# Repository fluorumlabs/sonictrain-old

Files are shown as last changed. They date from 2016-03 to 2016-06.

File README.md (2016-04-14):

# FluorumLabs / SonicTrain



This is the schematics and PCB repository for the second revision of SonicTrain: Hardware analog audio signal chain modules.

Version: 0.1-alpha2

Modules

Module | Revision | Status | Current Consumption (+15V / -15V) | Known issues
------ | -------- | ----------- | ------------ | ------- |
M101 Power Supply | B | Tested | | Polarity protection diode bridge is getting hot (50ºC) (#24)
M202 Stereo Input | C | Tested | 21mA / 35mA |
M303 Stereo Output | C | Tested | 31mA / 45mA |
M907 VU Meter | A | | |
M913 Dev Adapter | A | Tested | 5mA / 5mA | Blue LED is brighter then Red LED (#25)
A111 Fader | A | | |
A210 4-Band EQ | A | | |
A212 Kill EQ | A | | |
A405 Diode Distortion | A | Tested | 55mA / 60mA | Diodes should be connected to ground instead of OpAmp (#19), Output gain too low (#20)
A406 4069 Overdrive | A | | |
D104 LoFi Delay | A | Tested | |
D108 SpinSemi FX | A | Fail |  |
D709 VS1053 Synth | A | | |

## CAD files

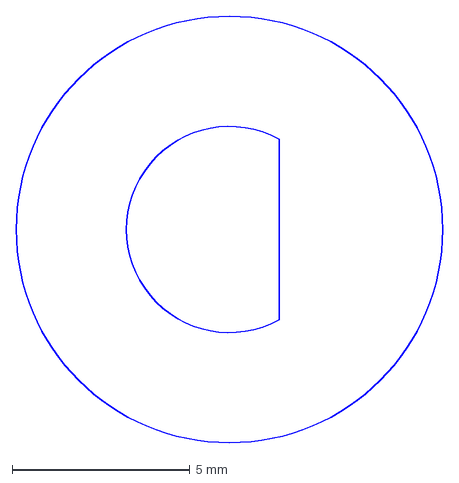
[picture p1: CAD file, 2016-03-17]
enclosure/w120-6045.dxf
12.0 x 12.0 mm

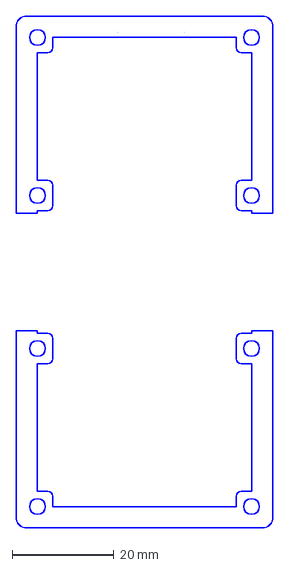
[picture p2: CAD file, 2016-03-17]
enclosure/z00003-5.dxf
50.4 x 100.4 mm

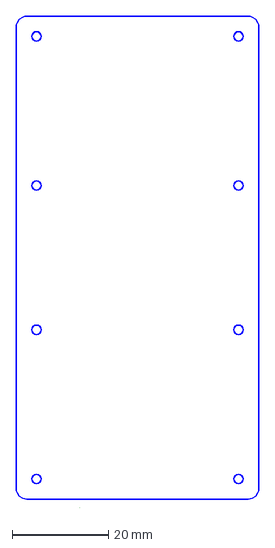
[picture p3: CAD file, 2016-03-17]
enclosure/z00001.dxf
50.4 x 102.2 mm

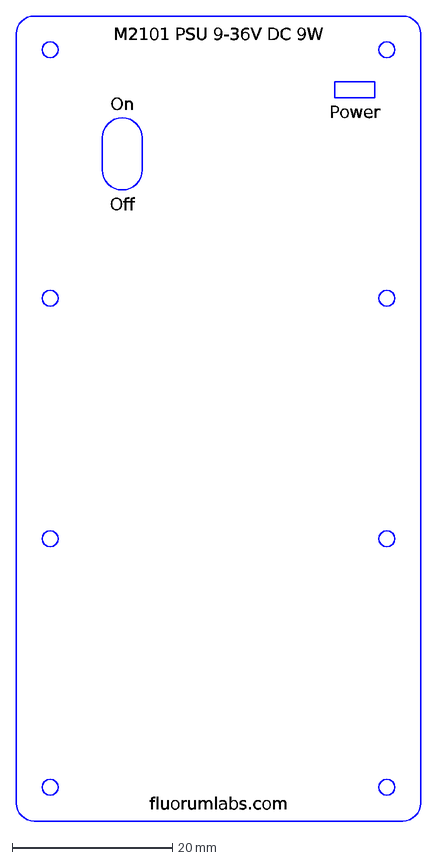
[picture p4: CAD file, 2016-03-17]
enclosure/m21016-switch.dxf
Power
fluorumlabs.com
M2101 PSU 9-36V DC 9W
On
Off

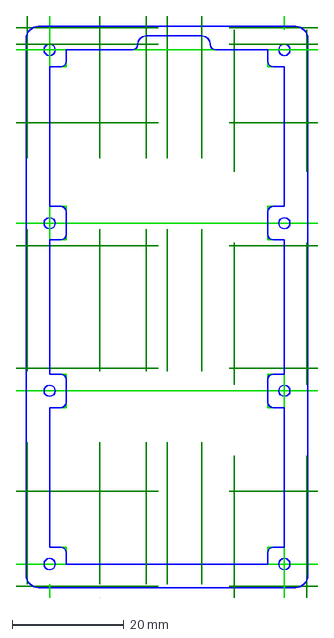
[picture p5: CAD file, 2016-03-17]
enclosure/m21012.dxf
54.0 x 104.0 mm

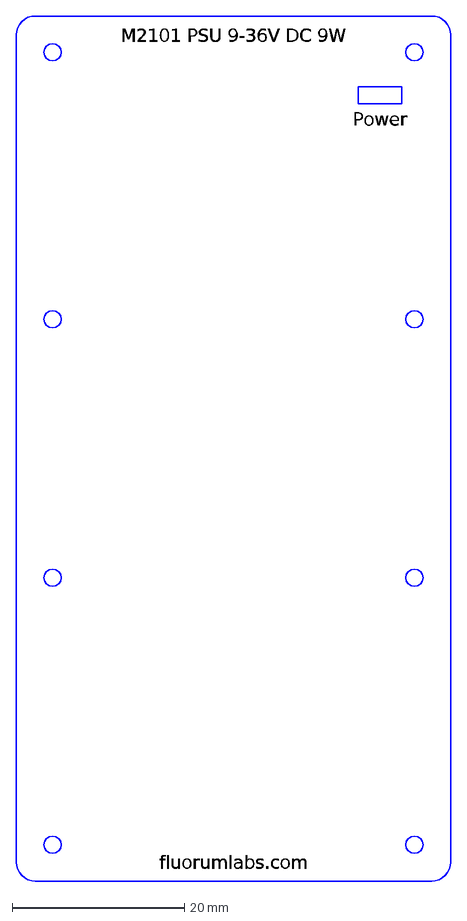
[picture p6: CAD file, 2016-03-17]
enclosure/m21016-no-switch.dxf
Power
fluorumlabs.com
M2101 PSU 9-36V DC 9W

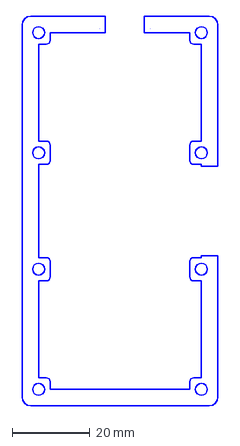
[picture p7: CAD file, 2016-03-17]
enclosure/m21013-5.dxf
50.4 x 100.4 mm

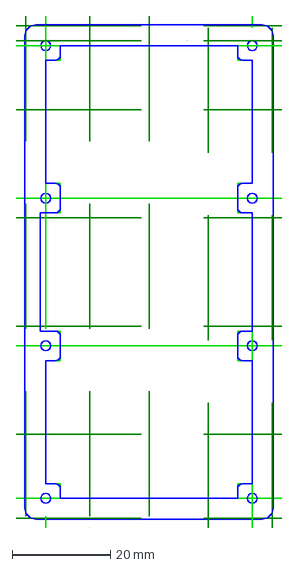
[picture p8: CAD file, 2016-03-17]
enclosure/z00002.dxf
54.0 x 104.0 mm

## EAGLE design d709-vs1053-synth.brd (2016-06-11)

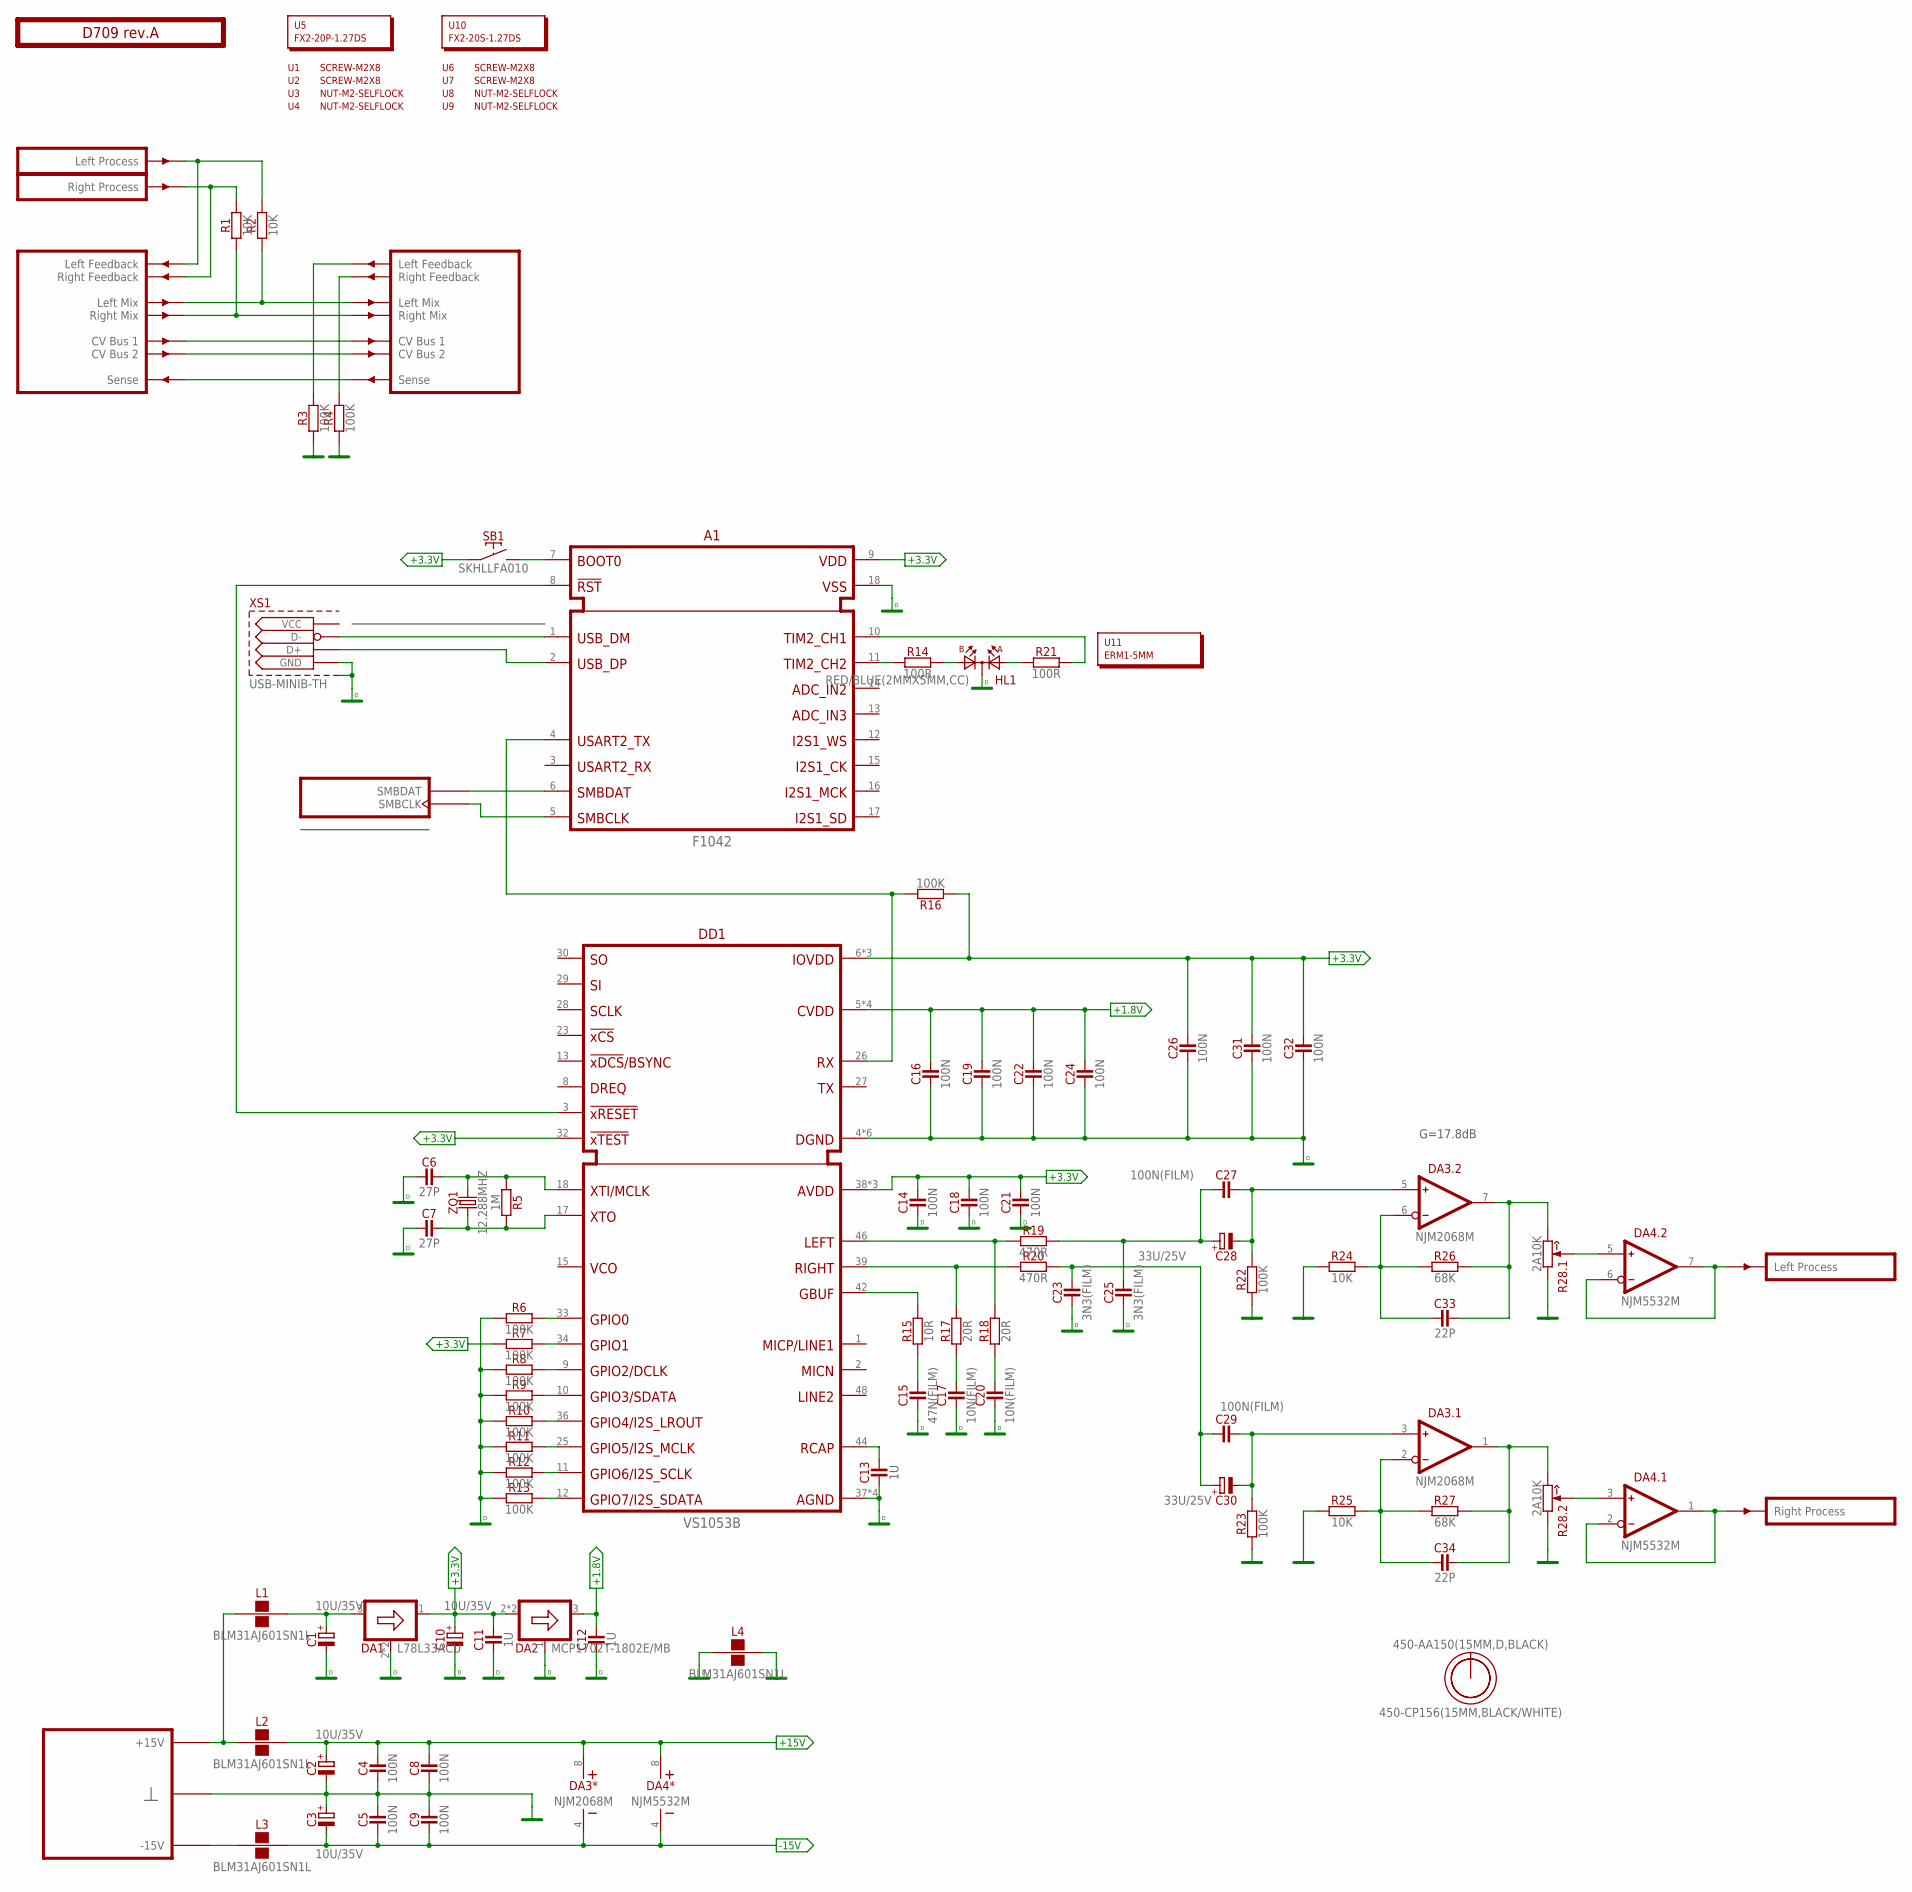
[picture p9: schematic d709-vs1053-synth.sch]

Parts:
A1: F1042; F-DIP18
C1, C2, C3, C10: 10U/35V; E2-5
C4, C5, C8, C9, C14, C16, C18, C19, C21, C22, C24, C26, C31, C32: 100N; C-0805
C6, C7: 27P; C-0805
C11, C12, C13: 1U; C-0805
C15: 47N(FILM); C050-025X075
C17, C20: 10N(FILM); C050-025X075
C23, C25: 3N3(FILM); C050-025X075
C27, C29: 100N(FILM); C050-025X075
C28, C30: 33U/25V; E2,5-7
C33, C34: 22P; C-0805
DA1: L78L33ACU; SOT89
DA2: MCP1702T-1802E/MB; SOT89
DA3: NJM2068M; SO-8
DA4: NJM5532M; SO-8
DD1: VS1053B; LQFP48-7X7
HL1: RED/BLUE(2MMX5MM,CC); LED2X5-3PIN
L1, L2, L3, L4: BLM31AJ601SN1L; 1206
O1: 450-AA150(15MM,D,BLACK); EMPTY
O2: 450-CP156(15MM,BLACK/WHITE); EMPTY
PCB1: D709 rev.A; ST2-BOARD-50
R1, R2, R24, R25: 10K; R-0805
R3, R4, R6, R7, R8, R9, R10, R11, R12, R13, R16, R22, R23: 100K; R-0805
R5: 1M; R-0805
R14, R21: 100R; R-0805
R15: 10R; R-0805
R17, R18: 20R; R-0805
R19, R20: 470R; R-0805
R26, R27: 68K; R-0805
R28: 2A10K; RV11-DUAL
SB1: SKHLLFA010
U1, U2, U6, U7: SCREW-M2X8; EMPTY
U3, U4, U8, U9: NUT-M2-SELFLOCK; EMPTY
U5: FX2-20P-1.27DS; EMPTY
U10: FX2-20S-1.27DS; EMPTY
U11: ERM1-5MM; EMPTY
XS1: USB-MINIB-TH; USB-MB-H
ZQ1: 12.288MHZ; 3225

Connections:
+1.8V: C12.2, C16.2, C19.2, C22.2, C24.2, DA2.3 (OUT), DD1.5 (CVDD), DD1.7 (CVDD), DD1.24 (CVDD), DD1.31 (CVDD)
+3.3V: A1.9 (VDD), C10.+, C11.2, C14.2, C18.2, C21.2, C26.2, C31.2, C32.2, DA1.1 (OUT), DA2.2 (IN), DA2.2@1 (IN), DD1.6 (IOVDD), DD1.14 (IOVDD), DD1.19 (IOVDD), DD1.32 (!XTEST), DD1.38 (AVDD), DD1.43 (AVDD), DD1.45 (AVDD), R7.1, R16.1, SB1.1
+15V: C2.+, C4.2, C8.2, DA3.8 (V+), DA4.8 (V+), L2.2
-15V: C3.-, C5.1, C9.1, DA3.4 (V-), DA4.4 (V-), L3.2
DGND: A1.18 (VSS), C1.-, C6.1, C7.1, C10.-, C11.1, C12.1, C13.1, C14.1, C15.1, C16.1, C17.1, C18.1, C19.1, C20.1, C21.1, C22.1, C23.1, C24.1, C25.1, C26.1, C31.1, C32.1, DA1.2 (GND), DA1.2@1 (GND), DA2.1 (GND), DD1.4 (DGND), DD1.16 (DGND), DD1.20 (DGND), DD1.21 (DGND), DD1.22 (DGND), DD1.35 (DGND), DD1.37 (AGND), DD1.40 (AGND), DD1.41 (AGND), DD1.47 (AGND), HL1.K, L4.1, R6.1, R8.1, R9.1, R10.1, R11.1, R12.1, R13.1, XS1.GND, XS1.P$1 (S1), XS1.P$2 (S1), XS1.P$6 (S1), XS1.P$7 (S1)
GND: C2.-, C3.+, C4.1, C5.2, C8.1, C9.2, L4.2, PCB1.B4 (GND), PCB1.B4' (GND), PCB1.B5 (GND), PCB1.B5' (GND), PCB1.B6 (GND), PCB1.B6' (GND), PCB1.B7 (GND), PCB1.B7' (GND), PCB1.B8 (GND), PCB1.B8' (GND), R3.1, R4.1, R22.1, R23.1, R24.1, R25.1, R28.1 (CCW), R28.1' (CCW)
LMIX: PCB1.ALMIX (LMIX), PCB1.ALMIX' (LMIX'), R2.1
unnamed: L1.1, L2.1, PCB1.A+15 (P+15V), PCB1.A+15' (P+15V), PCB1.B+15 (P+15V), PCB1.B+15' (P+15V)
unnamed: PCB1.ARFBK' (RFBK'), R4.2
unnamed: A1.7 (BOOT0), SB1.2
unnamed: PCB1.ALFBK' (LFBK'), R3.2
unnamed: L3.1, PCB1.A-15 (P-15V), PCB1.A-15' (P-15V), PCB1.B-15 (P-15V), PCB1.B-15' (P-15V)
unnamed: C25.2, C27.1, C28.+, R19.2
unnamed: C29.2, C30.-, DA3.3 (IN+), R23.2
unnamed: C27.2, C28.-, DA3.5 (IN+), R22.2
unnamed: C34.2, DA3.1 (OUT), R27.2, R28.3' (CW)
unnamed: C33.2, DA3.7 (OUT), R26.2, R28.3 (CW)
unnamed: C33.1, DA3.6 (IN-), R24.2, R26.1
unnamed: C34.1, DA3.2 (IN-), R25.2, R27.1
unnamed: PCB1.BSENSE (SENSE), PCB1.BSENSE' (SENSE')
unnamed: C7.2, DD1.17 (XTO), R5.2, ZQ1.1
unnamed: DA4.6 (IN-), DA4.7 (OUT), PCB1.BOUTL' (OUTL)
unnamed: DA4.1 (OUT), DA4.2 (IN-), PCB1.BOUTR' (OUTR)
unnamed: DA4.5 (IN+), R28.2 (W)
unnamed: DA4.3 (IN+), R28.2' (W)
unnamed: C1.+, DA1.3 (IN), L1.2
unnamed: C6.2, DD1.18 (XTI/MCLK), R5.1, ZQ1.3 (2)
unnamed: C23.2, C29.1, C30.+, R20.2
unnamed: PCB1.ARFBK (RFBK), PCB1.BINR (INR), R1.2
unnamed: PCB1.ALFBK (LFBK), PCB1.BINL (INL), R2.2
unnamed: PCB1.ACV1 (CV1), PCB1.ACV1' (CV1')
unnamed: PCB1.ACV2 (CV2), PCB1.ACV2' (CV2')
unnamed: A1.8 (!RST), DD1.3 (!XRESET)
unnamed: DD1.12 (GPIO7/I2S_SDATA), R13.2
unnamed: DD1.11 (GPIO6/I2S_SCLK), R12.2
unnamed: DD1.25 (GPIO5/I2S_MCLK), R11.2
unnamed: A1.4 (USART2_TX), DD1.26 (RX), R16.2
unnamed: DD1.36 (GPIO4/I2S_LROUT), R10.2
unnamed: DD1.10 (GPIO3/SDATA), R9.2
unnamed: DD1.9 (GPIO2/DCLK), R8.2
unnamed: DD1.34 (GPIO1), R7.2
unnamed: DD1.33 (GPIO0), R6.2
unnamed: C13.2, DD1.44 (RCAP)
unnamed: A1.11 (TIM2_CH2), R14.1
unnamed: C15.2, R15.1
unnamed: HL1.A2, R14.2
unnamed: DD1.42 (GBUF), R15.2
unnamed: DD1.39 (RIGHT), R17.2, R20.1
unnamed: C17.2, R17.1
unnamed: DD1.46 (LEFT), R18.2, R19.1
unnamed: C20.2, R18.1
unnamed: HL1.A1, R21.1
unnamed: A1.10 (TIM2_CH1), R21.2
RMIX: PCB1.ARMIX (RMIX), PCB1.ARMIX' (RMIX'), R1.1
SMBCLK: A1.5 (SMBCLK), PCB1.ASMBCLK (SMBCLK), PCB1.ASMBCLK' (SMBCLK)
SMBDAT: A1.6 (SBMDAT), PCB1.ASMBDAT (SMBDAT), PCB1.ASMBDAT' (SMBDAT)
USB_N: A1.1 (USB_DM), XS1.D-
USB_P: A1.2 (USB_DP), XS1.D+

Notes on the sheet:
G=17.8dB

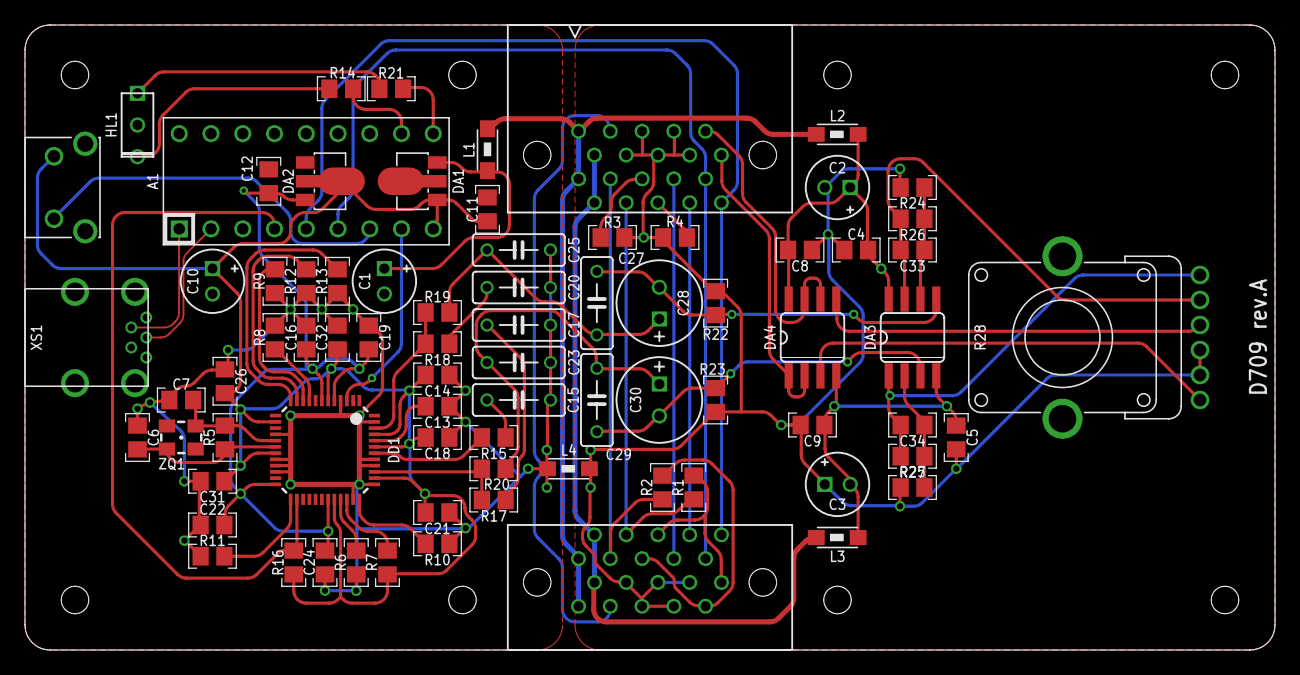
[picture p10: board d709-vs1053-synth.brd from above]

Board: 2 copper layers, 100.0 x 50.0 mm, 90 parts (0 on the bottom side), 58 nets.

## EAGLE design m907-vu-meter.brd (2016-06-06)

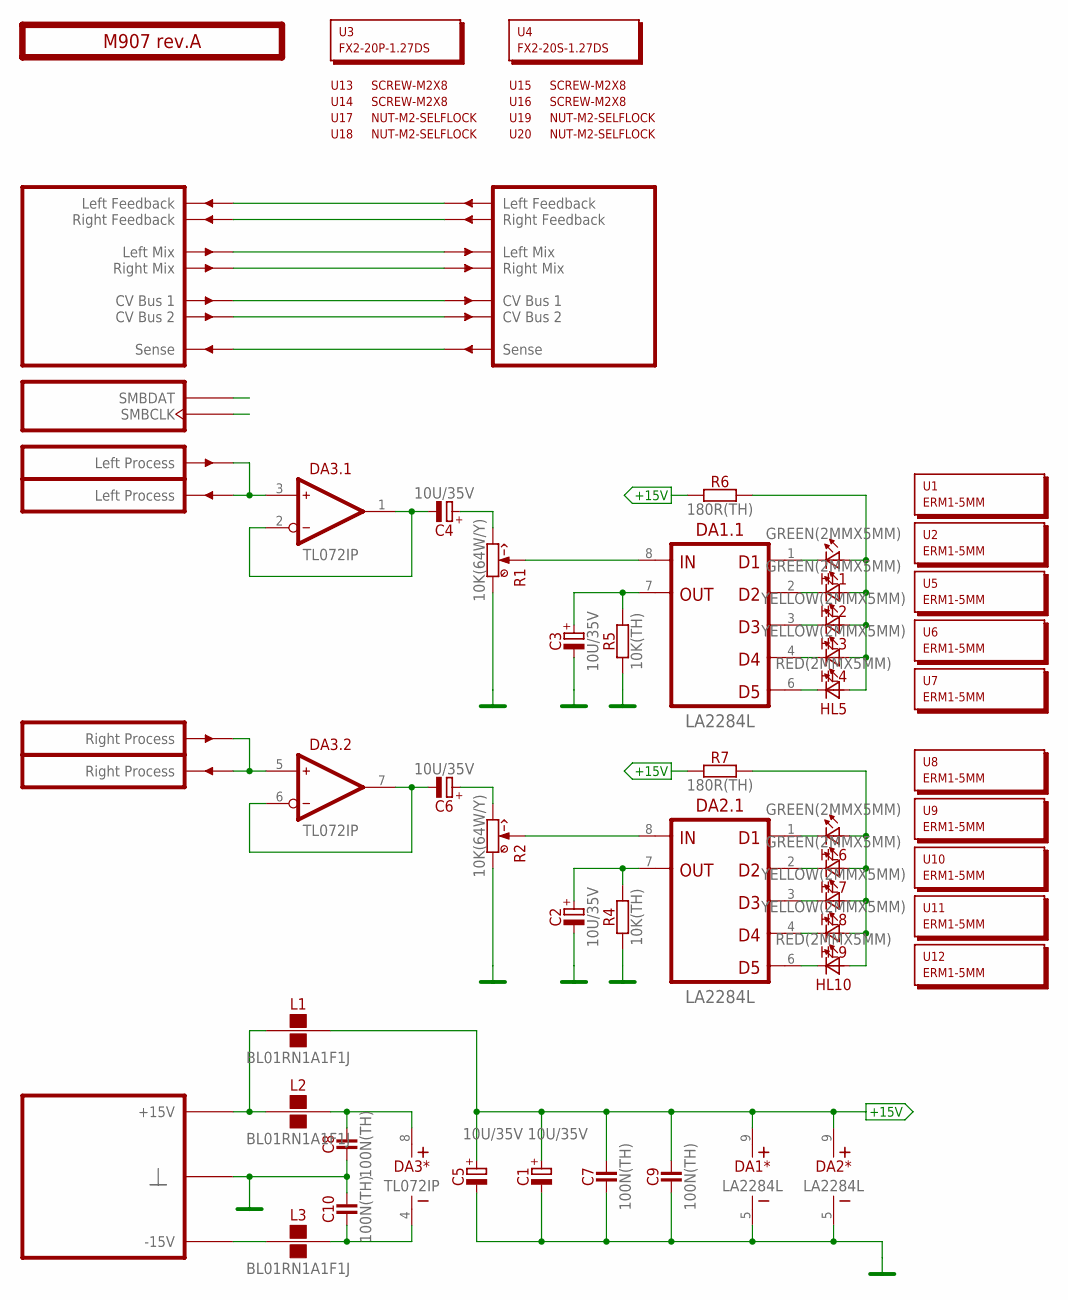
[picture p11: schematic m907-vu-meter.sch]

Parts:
C1, C2, C3, C4, C5, C6: 10U/35V; E2-5
C7, C8, C9, C10: 100N(TH); C050-024X044
DA1, DA2: LA2284L; SIL9
DA3: TL072IP; DIP-8
HL1, HL2, HL6, HL7: GREEN(2MMX5MM); LED2X5
HL3, HL4, HL8, HL9: YELLOW(2MMX5MM); LED2X5
HL5, HL10: RED(2MMX5MM); LED2X5
L1, L2, L3: BL01RN1A1F1J; BL01RN1A
PCB1: M907 rev.A; ST2-BOARD-26
R1, R2: 10K(64W/Y); 64W
R4, R5: 10K(TH); R-0207/10
R6, R7: 180R(TH); R-0207/10
U1, U2, U5, U6, U7, U8, U9, U10, U11, U12: ERM1-5MM; EMPTY
U3: FX2-20P-1.27DS; EMPTY
U4: FX2-20S-1.27DS; EMPTY
U13, U14, U15, U16: SCREW-M2X8; EMPTY
U17, U18, U19, U20: NUT-M2-SELFLOCK; EMPTY

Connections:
+15V: C1.+, C5.+, C7.2, C9.2, DA1.9 (V+), DA2.9 (V+), L1.2, R6.1, R7.1
GND: C1.-, C2.-, C3.-, C5.-, C7.1, C8.1, C9.1, C10.2, DA1.5 (V-), DA2.5 (V-), PCB1.B4 (GND), PCB1.B4' (GND), PCB1.B5 (GND), PCB1.B5' (GND), PCB1.B6 (GND), PCB1.B6' (GND), PCB1.B7 (GND), PCB1.B7' (GND), PCB1.B8 (GND), PCB1.B8' (GND), R1.1 (CCW), R2.1 (CCW), R4.1, R5.1
LMIX: PCB1.ALMIX (LMIX), PCB1.ALMIX' (LMIX')
unnamed: L1.1, L2.1, PCB1.A+15 (P+15V), PCB1.A+15' (P+15V), PCB1.B+15 (P+15V), PCB1.B+15' (P+15V)
unnamed: PCB1.ALFBK (LFBK), PCB1.ALFBK' (LFBK')
unnamed: DA2.8 (IN), R2.S (W), R2.S@1 (W)
unnamed: PCB1.ARFBK (RFBK), PCB1.ARFBK' (RFBK')
unnamed: DA1.8 (IN), R1.S (W), R1.S@1 (W)
unnamed: C3.+, DA1.7 (OUT), R5.2
unnamed: C2.+, DA2.7 (OUT), R4.2
unnamed: HL1.A, HL2.A, HL3.A, HL4.A, HL5.A, R6.2
unnamed: DA1.1 (D1), HL1.K (C)
unnamed: DA1.2 (D2), HL2.K (C)
unnamed: DA1.3 (D3), HL3.K (C)
unnamed: DA1.4 (D4), HL4.K (C)
unnamed: DA1.6 (D5), HL5.K (C)
unnamed: HL6.A, HL7.A, HL8.A, HL9.A, HL10.A, R7.2
unnamed: DA2.1 (D1), HL6.K (C)
unnamed: PCB1.BSENSE (SENSE), PCB1.BSENSE' (SENSE')
unnamed: DA2.2 (D2), HL7.K (C)
unnamed: DA2.3 (D3), HL8.K (C)
unnamed: DA2.4 (D4), HL9.K (C)
unnamed: DA2.6 (D5), HL10.K (C)
unnamed: C4.+, R1.3 (CW)
unnamed: C6.+, R2.3 (CW)
unnamed: DA3.3 (IN+), PCB1.BINL (INL), PCB1.BOUTL' (OUTL)
unnamed: DA3.5 (IN+), PCB1.BINR (INR), PCB1.BOUTR' (OUTR)
unnamed: L3.1, PCB1.A-15 (P-15V), PCB1.A-15' (P-15V), PCB1.B-15 (P-15V), PCB1.B-15' (P-15V)
unnamed: C8.2, DA3.8 (V+), L2.2
unnamed: C10.1, DA3.4 (V-), L3.2
unnamed: C4.-, DA3.1 (OUT), DA3.2 (IN-)
unnamed: C6.-, DA3.6 (IN-), DA3.7 (OUT)
unnamed: PCB1.ASMBDAT (SMBDAT), PCB1.ASMBDAT' (SMBDAT)
unnamed: PCB1.ACV1 (CV1), PCB1.ACV1' (CV1')
unnamed: PCB1.ACV2 (CV2), PCB1.ACV2' (CV2')
unnamed: PCB1.ASMBCLK (SMBCLK), PCB1.ASMBCLK' (SMBCLK)
RMIX: PCB1.ARMIX (RMIX), PCB1.ARMIX' (RMIX')

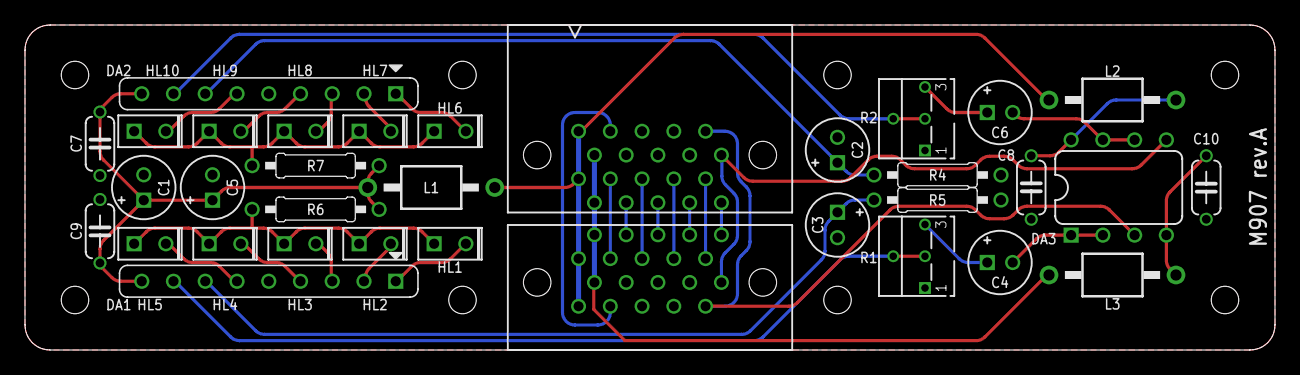
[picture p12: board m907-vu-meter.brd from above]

Board: 2 copper layers, 100.0 x 26.0 mm, 53 parts (0 on the bottom side), 37 nets.

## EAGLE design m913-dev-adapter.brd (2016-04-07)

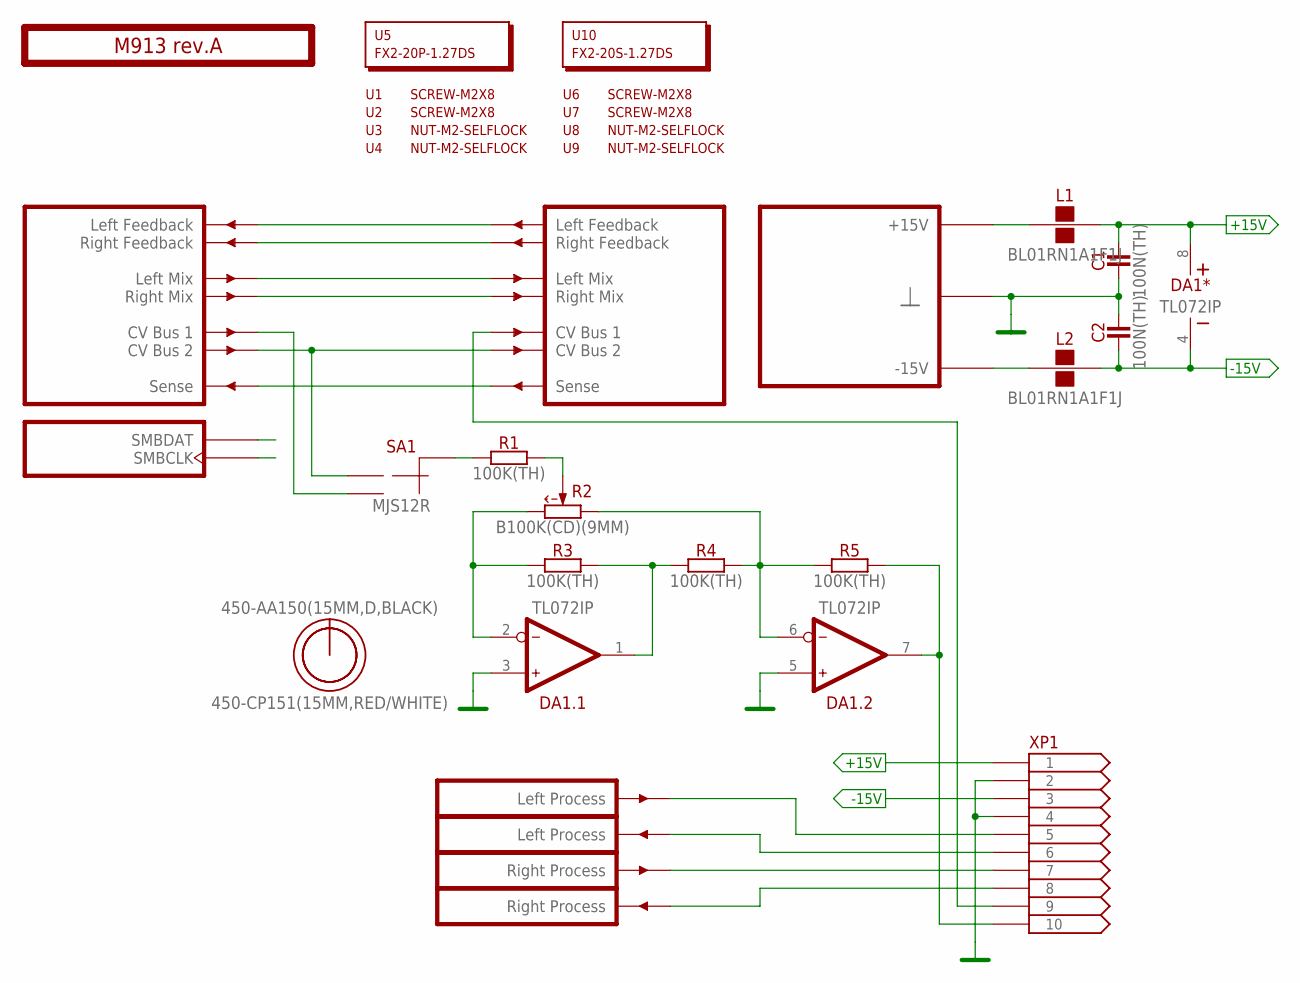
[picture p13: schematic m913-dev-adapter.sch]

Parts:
C1, C2: 100N(TH); C050-024X044
DA1: TL072IP; DIP-8
L1, L2: BL01RN1A1F1J; BL01RN1A
O1: 450-AA150(15MM,D,BLACK); EMPTY
O2: 450-CP151(15MM,RED/WHITE); EMPTY
PCB1: M913 rev.A; ST2-BOARD-26
R1, R3, R4, R5: 100K(TH); R-0207/10
R2: B100K(CD)(9MM); RV09-SINGLE
SA1: MJS12R; APEM-MJS12R
U1, U2, U6, U7: SCREW-M2X8; EMPTY
U3, U4, U8, U9: NUT-M2-SELFLOCK; EMPTY
U5: FX2-20P-1.27DS; EMPTY
U10: FX2-20S-1.27DS; EMPTY
XP1: CONN-10-IDC; ML10

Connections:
+15V: C1.2, DA1.8 (V+), L1.2, XP1.1
-15V: C2.1, DA1.4 (V-), L2.2, XP1.3
GND: C1.1, C2.2, DA1.3 (IN+), DA1.5 (IN+), PCB1.B4 (GND), PCB1.B4' (GND), PCB1.B5 (GND), PCB1.B5' (GND), PCB1.B6 (GND), PCB1.B6' (GND), PCB1.B7 (GND), PCB1.B7' (GND), PCB1.B8 (GND), PCB1.B8' (GND), XP1.2, XP1.4
LMIX: PCB1.ALMIX (LMIX), PCB1.ALMIX' (LMIX')
unnamed: L1.1, PCB1.A+15 (P+15V), PCB1.A+15' (P+15V), PCB1.B+15 (P+15V), PCB1.B+15' (P+15V)
unnamed: PCB1.ALFBK (LFBK), PCB1.ALFBK' (LFBK')
unnamed: R1.2, R2.2 (W)
unnamed: PCB1.ARFBK (RFBK), PCB1.ARFBK' (RFBK')
unnamed: DA1.2 (IN-), R2.3 (CW), R3.1
unnamed: DA1.1 (OUT), R3.2, R4.1
unnamed: DA1.6 (IN-), R2.1 (CCW), R4.2, R5.1
unnamed: DA1.7 (OUT), R5.2, XP1.10
unnamed: R1.1, SA1.C (CM)
unnamed: PCB1.BINL (INL), XP1.5
unnamed: PCB1.BOUTL' (OUTL), XP1.6
unnamed: PCB1.BINR (INR), XP1.7
unnamed: PCB1.BOUTR' (OUTR), XP1.8
unnamed: PCB1.ACV1' (CV1'), XP1.9
unnamed: PCB1.ACV1 (CV1), SA1.NO (2)
unnamed: PCB1.BSENSE (SENSE), PCB1.BSENSE' (SENSE')
unnamed: L2.1, PCB1.A-15 (P-15V), PCB1.A-15' (P-15V), PCB1.B-15 (P-15V), PCB1.B-15' (P-15V)
unnamed: PCB1.ASMBDAT (SMBDAT), PCB1.ASMBDAT' (SMBDAT)
unnamed: PCB1.ACV2 (CV2), PCB1.ACV2' (CV2'), SA1.NC (1)
unnamed: PCB1.ASMBCLK (SMBCLK), PCB1.ASMBCLK' (SMBCLK)
RMIX: PCB1.ARMIX (RMIX), PCB1.ARMIX' (RMIX')

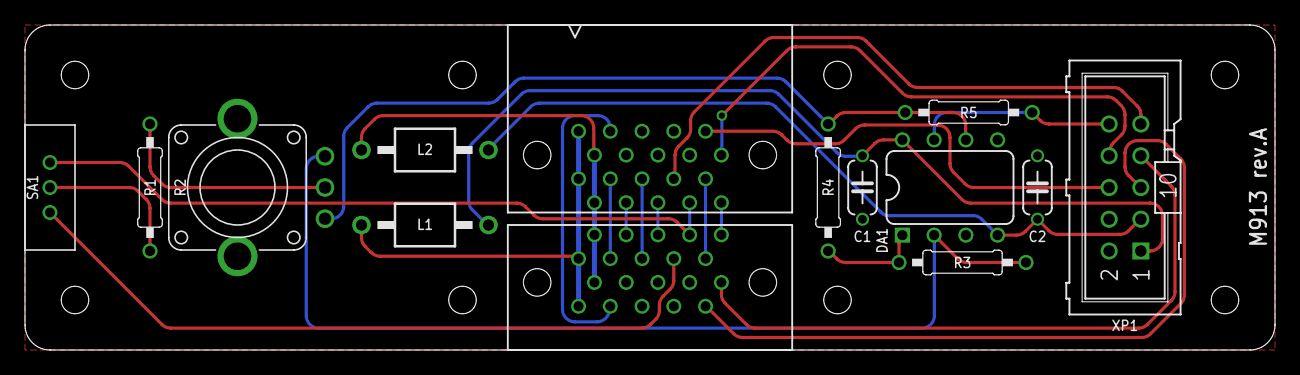
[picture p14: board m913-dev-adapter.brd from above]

Board: 2 copper layers, 100.0 x 26.0 mm, 25 parts (0 on the bottom side), 25 nets.

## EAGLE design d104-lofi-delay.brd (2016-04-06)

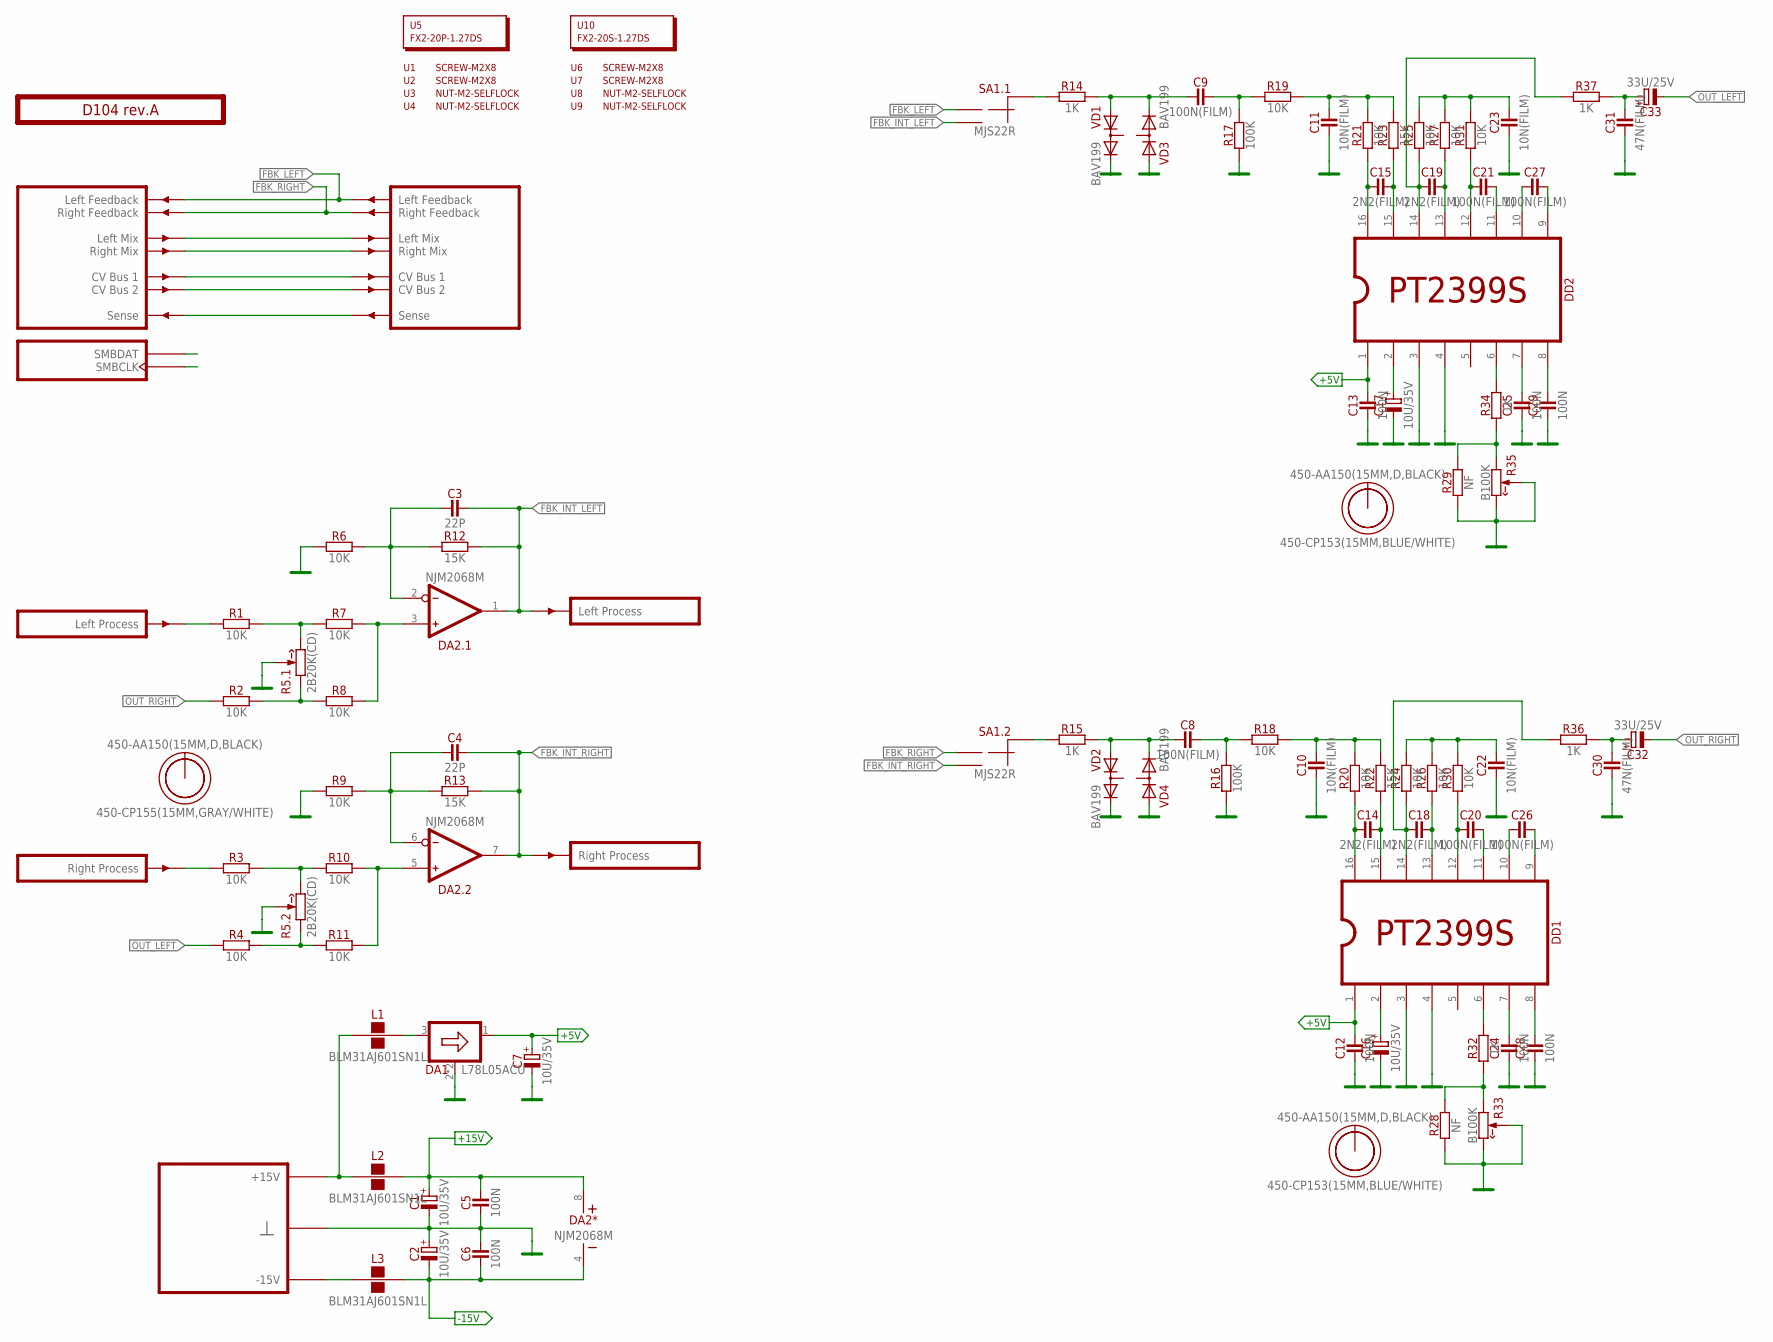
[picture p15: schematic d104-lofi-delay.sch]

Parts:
C1, C2, C7, C16, C17: 10U/35V; E2-5
C3, C4: 22P; C-0805
C5, C6, C12, C13, C24, C25, C28, C29: 100N; C-0805
C8, C9, C20, C21, C26, C27: 100N(FILM); C050-025X075
C10, C11, C22, C23: 10N(FILM); C050-025X075
C14, C15, C18, C19: 2N2(FILM); C050-025X075
C30, C31: 47N(FILM); C050-025X075
C32, C33: 33U/25V; E2,5-7
DA1: L78L05ACU; SOT89
DA2: NJM2068M; SO-8
DD1, DD2: PT2399S; SO-16; PARTNO *
L1, L2, L3: BLM31AJ601SN1L; 1206
O1, O3, O5: 450-AA150(15MM,D,BLACK); EMPTY
O2: 450-CP155(15MM,GRAY/WHITE); EMPTY
O4, O6: 450-CP153(15MM,BLUE/WHITE); EMPTY
PCB1: D104 rev.A; ST2-BOARD-50
R1, R2, R3, R4, R6, R7, R8, R9, R10, R11, R18, R19, R20, R21, R24, R25, R26, R27, R30, R31: 10K; R-0805
R5: 2B20K(CD); RV11-DUAL
R12, R13, R22, R23: 15K; R-0805
R14, R15, R32, R34, R36, R37: 1K; R-0805
R16, R17: 100K; R-0805
R28, R29: NF; R-0805
R33, R35: B100K; RV11-SINGLE
SA1: MJS22R; APEM-MJS22R
U1, U2, U6, U7: SCREW-M2X8; EMPTY
U3, U4, U8, U9: NUT-M2-SELFLOCK; EMPTY
U5: FX2-20P-1.27DS; EMPTY
U10: FX2-20S-1.27DS; EMPTY
VD1, VD2, VD3, VD4: BAV199; SOT23

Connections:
+5V: C7.+, C12.2, C13.2, DA1.1 (OUT), DD1.1, DD2.1
+15V: C1.+, C5.2, DA2.8 (V+), L2.2
-15V: C2.-, C6.1, DA2.4 (V-), L3.2
FBK_INT_LEFT: C3.2, DA2.1 (OUT), PCB1.BOUTL' (OUTL), R12.2, SA1.NO1 (2)
FBK_INT_RIGHT: C4.2, DA2.7 (OUT), PCB1.BOUTR' (OUTR), R13.2, SA1.NO2 (2)
FBK_LEFT: PCB1.ALFBK (LFBK), PCB1.ALFBK' (LFBK'), SA1.NC1 (1)
FBK_RIGHT: PCB1.ARFBK (RFBK), PCB1.ARFBK' (RFBK'), SA1.NC2 (1)
GND: C1.-, C2.+, C5.1, C6.2, C7.-, C10.1, C11.1, C12.1, C13.1, C16.-, C17.-, C22.1, C23.1, C24.1, C25.1, C28.1, C29.1, C30.1, C31.1, DA1.2 (GND), DA1.2@1 (GND), DD1.3, DD1.4, DD2.3, DD2.4, PCB1.B4 (GND), PCB1.B4' (GND), PCB1.B5 (GND), PCB1.B5' (GND), PCB1.B6 (GND), PCB1.B6' (GND), PCB1.B7 (GND), PCB1.B7' (GND), PCB1.B8 (GND), PCB1.B8' (GND), R5.2 (W), R5.2' (W), R6.1, R9.1, R16.1, R17.1, R28.1, R29.1, R33.2 (W), R33.3 (CW), R35.2 (W), R35.3 (CW), VD1.2 (C), VD2.2 (C), VD3.1 (A), VD4.1 (A)
LMIX: PCB1.ALMIX (LMIX), PCB1.ALMIX' (LMIX')
unnamed: R29.2, R34.1, R35.1 (CCW)
unnamed: R28.2, R32.1, R33.1 (CCW)
unnamed: C9.1, R14.2, VD1.1 (A), VD3.2 (C)
unnamed: C15.1, DD2.16, R21.1
unnamed: C8.1, R15.2, VD2.1 (A), VD4.2 (C)
unnamed: R14.1, SA1.C1 (CM)
unnamed: R3.2, R5.3' (CW), R10.1
unnamed: C9.2, R17.2, R19.1
unnamed: C11.2, R19.2, R21.2, R23.2
unnamed: PCB1.BINL (INL), R1.1
unnamed: R15.1, SA1.C2 (CM)
unnamed: C23.2, R25.2, R27.2, R31.2
unnamed: PCB1.BSENSE (SENSE), PCB1.BSENSE' (SENSE')
unnamed: C15.2, DD2.15, R23.1
unnamed: C19.1, DD2.14, R25.1, R37.1
unnamed: C19.2, DD2.13, R27.1
unnamed: C21.1, DD2.12, R31.1
unnamed: C21.2, DD2.11
unnamed: C27.1, DD2.10
unnamed: C27.2, DD2.9
unnamed: C31.2, C33.+, R37.2
unnamed: C4.1, DA2.6 (IN-), R9.2, R13.1
unnamed: PCB1.BINR (INR), R3.1
unnamed: R1.2, R5.3 (CW), R7.1
unnamed: C25.2, DD2.7
unnamed: C29.2, DD2.8
unnamed: DD2.6, R34.2
unnamed: L3.1, PCB1.A-15 (P-15V), PCB1.A-15' (P-15V), PCB1.B-15 (P-15V), PCB1.B-15' (P-15V)
unnamed: C17.+, DD2.2
unnamed: PCB1.ASMBDAT (SMBDAT), PCB1.ASMBDAT' (SMBDAT)
unnamed: DA2.5 (IN+), R10.2, R11.2
unnamed: R4.2, R5.1' (CCW), R11.1
unnamed: PCB1.ACV1 (CV1), PCB1.ACV1' (CV1')
unnamed: PCB1.ACV2 (CV2), PCB1.ACV2' (CV2')
unnamed: PCB1.ASMBCLK (SMBCLK), PCB1.ASMBCLK' (SMBCLK)
unnamed: DA1.3 (IN), L1.2
unnamed: C22.2, R24.2, R26.2, R30.2
unnamed: C14.1, DD1.16, R20.1
unnamed: C14.2, DD1.15, R22.1
unnamed: C18.1, DD1.14, R24.1, R36.1
unnamed: C18.2, DD1.13, R26.1
unnamed: C20.1, DD1.12, R30.1
unnamed: C20.2, DD1.11
unnamed: C26.1, DD1.10
unnamed: C26.2, DD1.9
unnamed: C30.2, C32.+, R36.2
unnamed: C24.2, DD1.7
unnamed: C28.2, DD1.8
unnamed: DD1.6, R32.2
unnamed: DA2.3 (IN+), R7.2, R8.2
unnamed: C8.2, R16.2, R18.1
unnamed: C10.2, R18.2, R20.2, R22.2
unnamed: C3.1, DA2.2 (IN-), R6.2, R12.1
unnamed: R2.2, R5.1 (CCW), R8.1
unnamed: C16.+, DD1.2
OUT_LEFT: C33.-, R4.1
OUT_RIGHT: C32.-, R2.1
P+15V: L1.1, L2.1, PCB1.A+15 (P+15V), PCB1.A+15' (P+15V), PCB1.B+15 (P+15V), PCB1.B+15' (P+15V)
RMIX: PCB1.ARMIX (RMIX), PCB1.ARMIX' (RMIX')

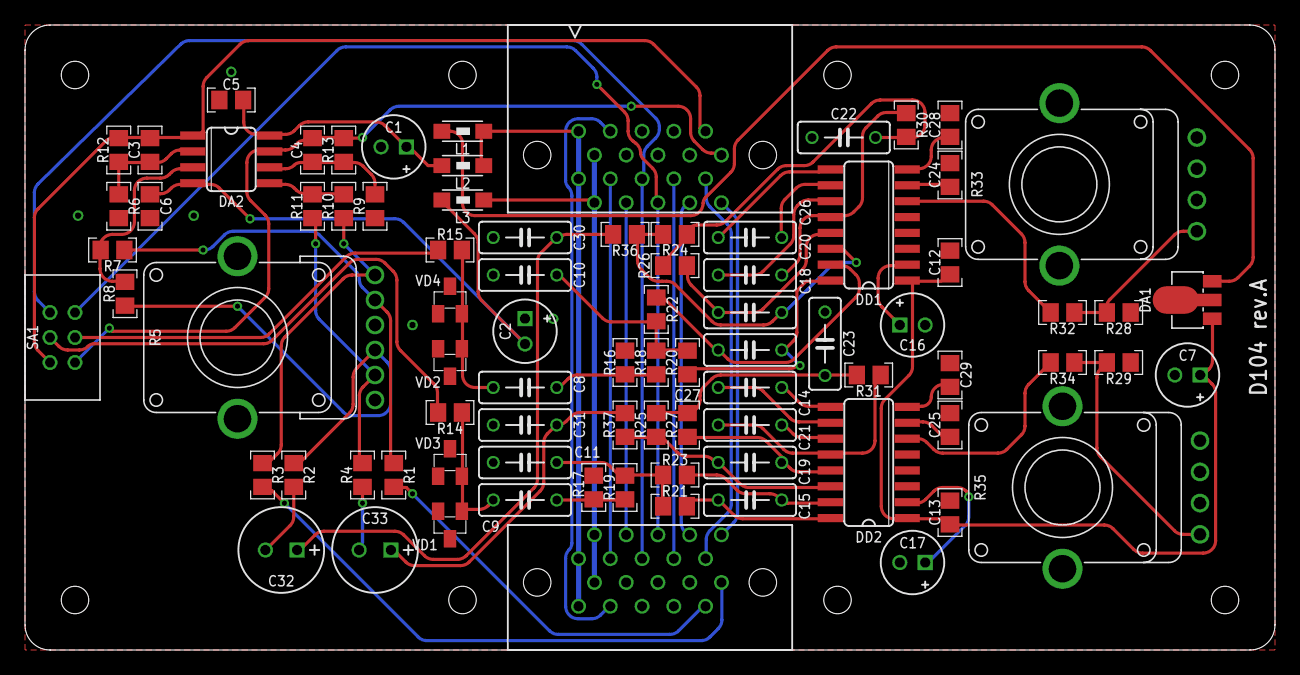
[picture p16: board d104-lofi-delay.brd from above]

Board: 2 copper layers, 100.0 x 50.0 mm, 99 parts (0 on the bottom side), 68 nets.

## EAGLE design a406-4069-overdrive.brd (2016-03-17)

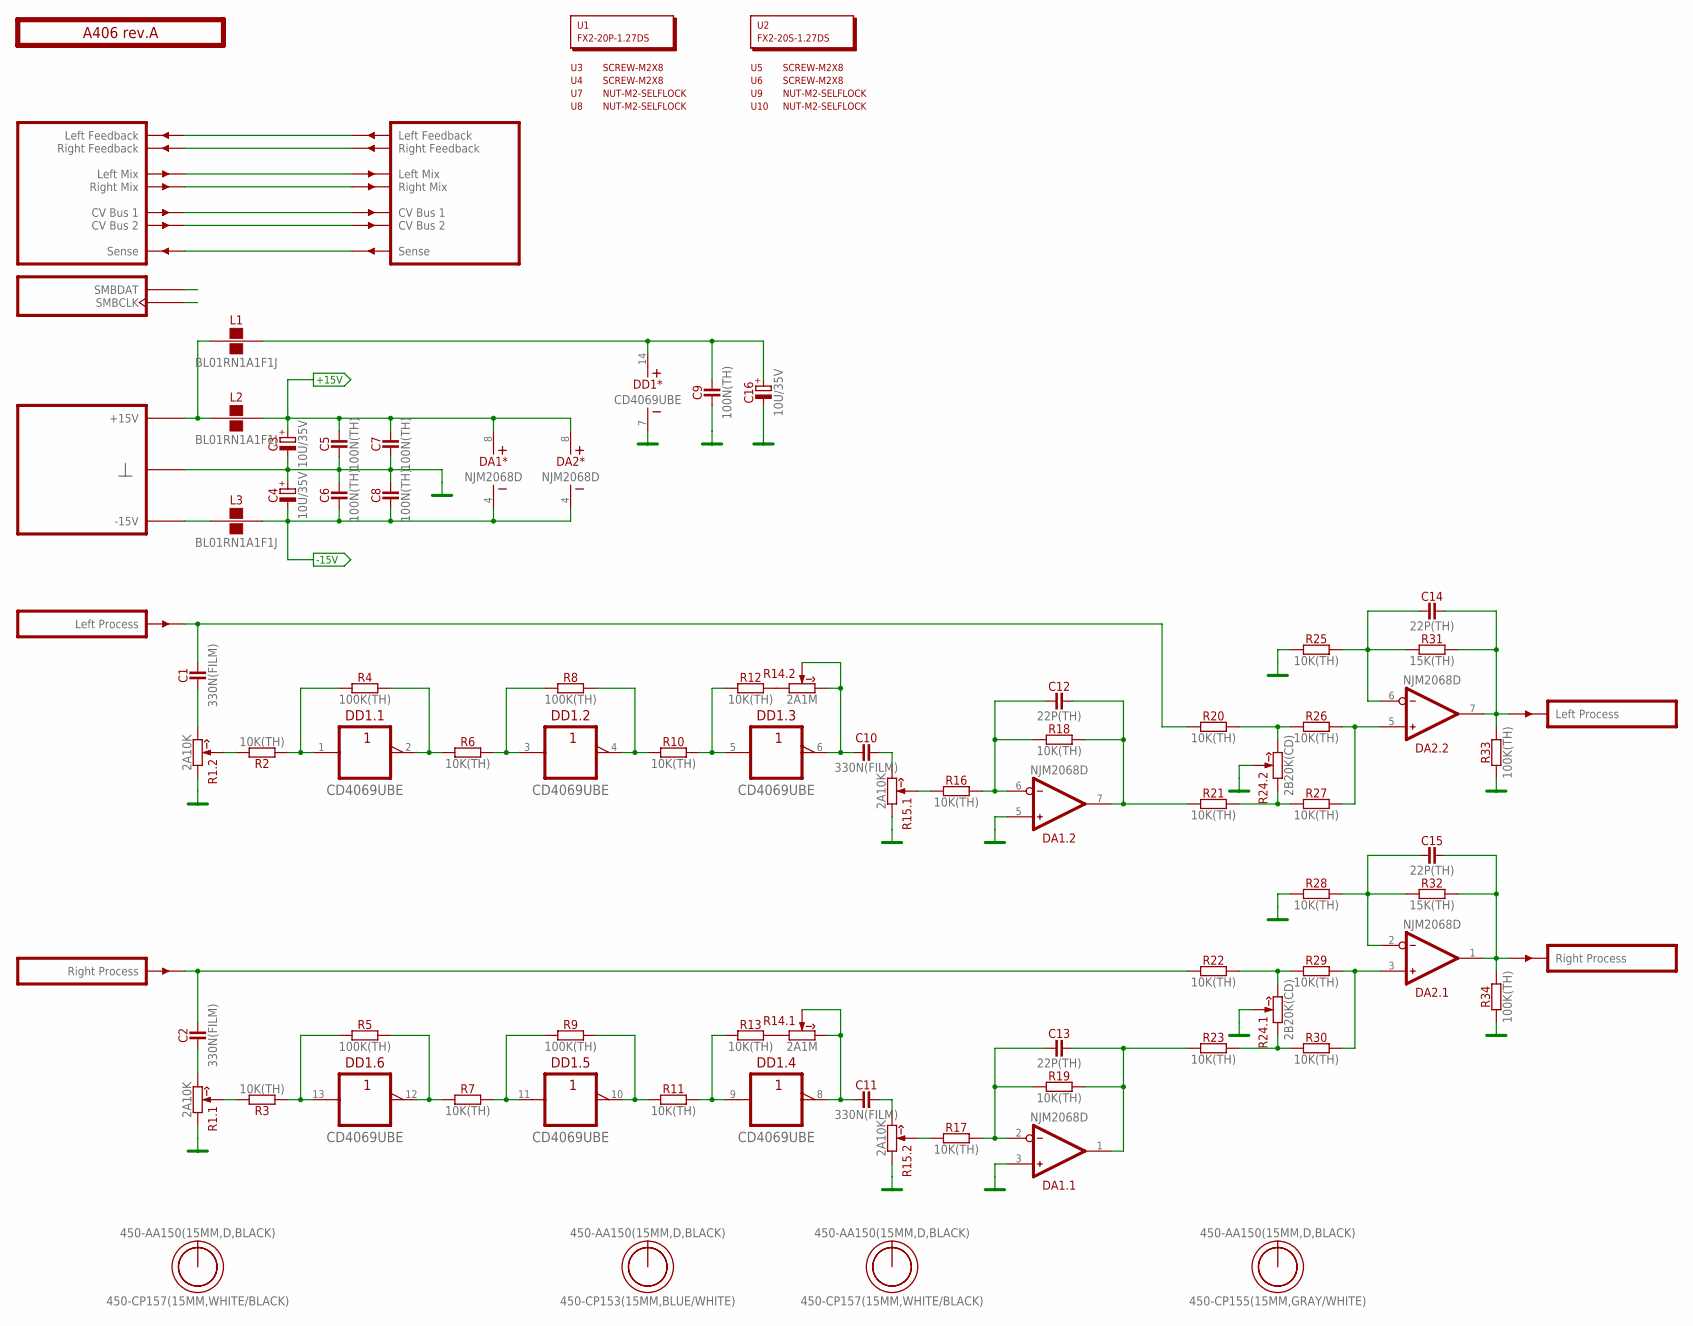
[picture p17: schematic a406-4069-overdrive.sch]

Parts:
C1, C2, C10, C11: 330N(FILM); C050-035X075
C3, C4, C16: 10U/35V; E2-5
C5, C6, C7, C8, C9: 100N(TH); C050-024X044
C12, C13, C14, C15: 22P(TH); C050-024X044
DA1, DA2: NJM2068D; DIP-8
DD1: CD4069UBE; DIP-14
L1, L2, L3: BL01RN1A1F1J; BL01RN1A
O2, O4, O6, O8: 450-AA150(15MM,D,BLACK); EMPTY
O3, O7: 450-CP157(15MM,WHITE/BLACK); EMPTY
O5: 450-CP153(15MM,BLUE/WHITE); EMPTY
O9: 450-CP155(15MM,GRAY/WHITE); EMPTY
PCB1: A406 rev.A; ST2-BOARD-50
R1, R15: 2A10K; RV11-DUAL
R2, R3, R6, R7, R10, R11, R12, R13, R16, R17, R18, R19, R20, R21, R22, R23, R25, R26, R27, R28, R29, R30: 10K(TH); R-0207/10
R4, R5, R8, R9, R33, R34: 100K(TH); R-0207/10
R14: 2A1M; RV11-DUAL
R24: 2B20K(CD); RV11-DUAL
R31, R32: 15K(TH); R-0207/10
U1: FX2-20P-1.27DS; EMPTY
U2: FX2-20S-1.27DS; EMPTY
U3, U4, U5, U6: SCREW-M2X8; EMPTY
U7, U8, U9, U10: NUT-M2-SELFLOCK; EMPTY

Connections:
+15V: C3.+, C5.2, C7.2, DA1.8 (V+), DA2.8 (V+), L2.2
-15V: C4.-, C6.1, C8.1, DA1.4 (V-), DA2.4 (V-), L3.2
FBK_LEFT: PCB1.ALFBK (LFBK), PCB1.ALFBK' (LFBK')
FBK_RIGHT: PCB1.ARFBK (RFBK), PCB1.ARFBK' (RFBK')
GND: C3.-, C4.+, C5.1, C6.2, C7.1, C8.2, C9.1, C16.-, DA1.3 (IN+), DA1.5 (IN+), DD1.7 (V-), PCB1.B4 (GND), PCB1.B4' (GND), PCB1.B5 (GND), PCB1.B5' (GND), PCB1.B6 (GND), PCB1.B6' (GND), PCB1.B7 (GND), PCB1.B7' (GND), PCB1.B8 (GND), PCB1.B8' (GND), R1.1 (CCW), R1.1' (CCW), R15.1 (CCW), R15.1' (CCW), R24.2 (W), R24.2' (W), R25.1, R28.1, R33.1, R34.1
LMIX: PCB1.ALMIX (LMIX), PCB1.ALMIX' (LMIX')
unnamed: C9.2, C16.+, DD1.14 (V+), L1.2
unnamed: R12.2, R14.1' (CCW)
unnamed: R13.2, R14.1 (CCW)
unnamed: C1.2, PCB1.BINL (INL), R20.1
unnamed: C1.1, R1.3' (CW)
unnamed: DD1.1 (A), R2.1, R4.1
unnamed: DD1.2 (Y), R4.2, R6.1
unnamed: DD1.3 (A), R6.2, R8.1
unnamed: DD1.4 (Y), R8.2, R10.1
unnamed: DD1.5 (A), R10.2, R12.1
unnamed: C10.1, DD1.6 (Y), R14.2' (W), R14.3' (CW)
unnamed: C10.2, R15.3 (CW)
unnamed: R15.2 (W), R16.1
unnamed: C12.1, DA1.6 (IN-), R16.2, R18.1
unnamed: R1.2' (W), R2.2
unnamed: PCB1.BSENSE (SENSE), PCB1.BSENSE' (SENSE')
unnamed: C12.2, DA1.7 (OUT), R18.2, R21.1
unnamed: C2.1, R1.3 (CW)
unnamed: C2.2, PCB1.BINR (INR), R22.1
unnamed: R1.2 (W), R3.2
unnamed: DD1.13 (A), R3.1, R5.1
unnamed: DD1.12 (Y), R5.2, R7.1
unnamed: DD1.11 (A), R7.2, R9.1
unnamed: DD1.10 (Y), R9.2, R11.1
unnamed: DD1.9 (A), R11.2, R13.1
unnamed: C11.1, DD1.8 (Y), R14.2 (W), R14.3 (CW)
unnamed: C14.2, DA2.7 (OUT), PCB1.BOUTL' (OUTL), R31.2, R33.2
unnamed: C11.2, R15.3' (CW)
unnamed: R15.2' (W), R17.1
unnamed: C13.1, DA1.2 (IN-), R17.2, R19.1
unnamed: C13.2, DA1.1 (OUT), R19.2, R23.1
unnamed: R20.2, R24.3' (CW), R26.1
unnamed: R22.2, R24.3 (CW), R29.1
unnamed: C15.1, DA2.2 (IN-), R28.2, R32.1
unnamed: L3.1, PCB1.A-15 (P-15V), PCB1.A-15' (P-15V), PCB1.B-15 (P-15V), PCB1.B-15' (P-15V)
unnamed: C15.2, DA2.1 (OUT), PCB1.BOUTR' (OUTR), R32.2, R34.2
unnamed: PCB1.ASMBDAT (SMBDAT), PCB1.ASMBDAT' (SMBDAT)
unnamed: DA2.3 (IN+), R29.2, R30.2
unnamed: R23.2, R24.1 (CCW), R30.1
unnamed: PCB1.ACV1 (CV1), PCB1.ACV1' (CV1')
unnamed: PCB1.ACV2 (CV2), PCB1.ACV2' (CV2')
unnamed: PCB1.ASMBCLK (SMBCLK), PCB1.ASMBCLK' (SMBCLK)
unnamed: DA2.5 (IN+), R26.2, R27.2
unnamed: C14.1, DA2.6 (IN-), R25.2, R31.1
unnamed: R21.2, R24.1' (CCW), R27.1
P+15V: L1.1, L2.1, PCB1.A+15 (P+15V), PCB1.A+15' (P+15V), PCB1.B+15 (P+15V), PCB1.B+15' (P+15V)
RMIX: PCB1.ARMIX (RMIX), PCB1.ARMIX' (RMIX')

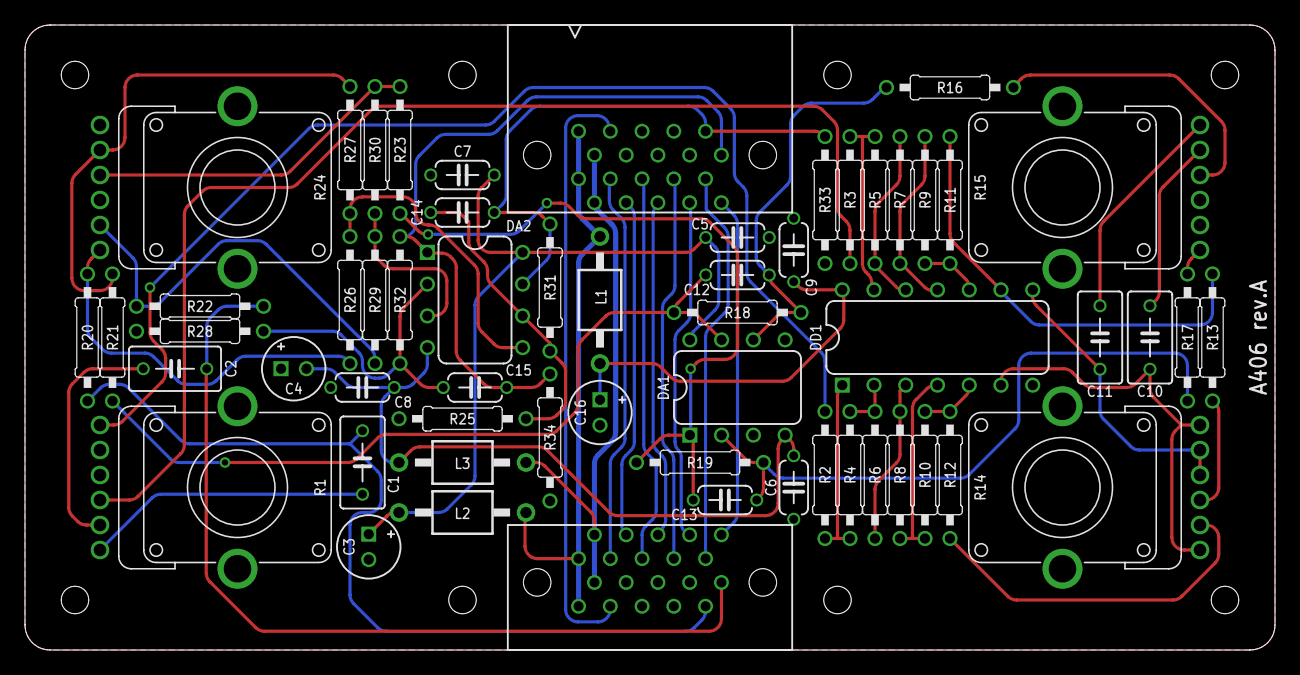
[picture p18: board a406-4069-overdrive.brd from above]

Board: 2 copper layers, 100.0 x 50.0 mm, 75 parts (0 on the bottom side), 53 nets.

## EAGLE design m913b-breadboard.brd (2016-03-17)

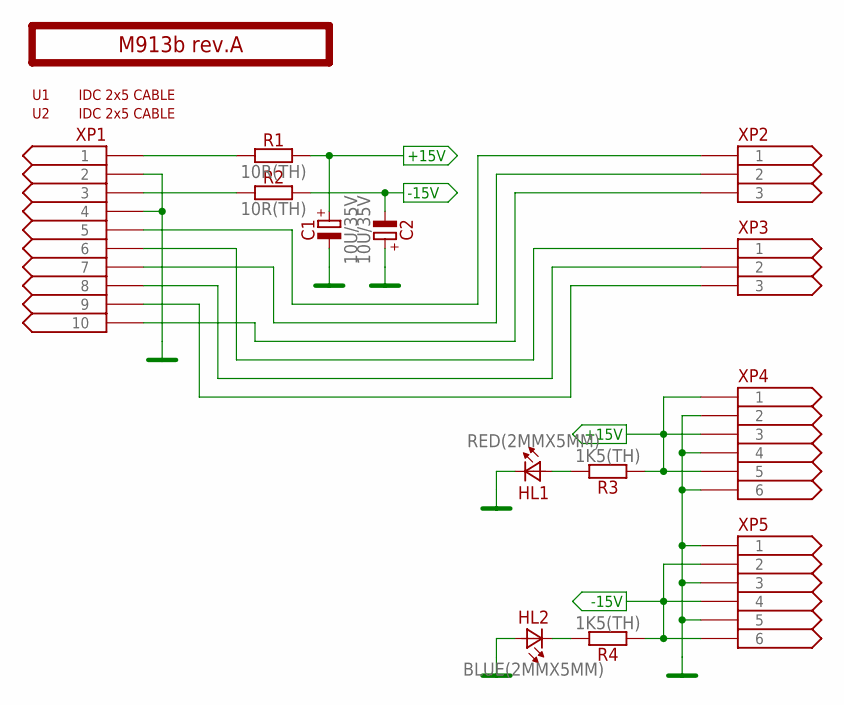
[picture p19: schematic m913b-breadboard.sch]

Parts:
C1, C2: 10U/35V; E2-5
HL1: RED(2MMX5MM); LED2X5
HL2: BLUE(2MMX5MM); LED2X5
PCB1: M913b rev.A; EMPTY
R1, R2: 10R(TH); R-0207/10
R3, R4: 1K5(TH); R-0207/10
U1, U2: IDC 2x5 CABLE; EMPTY
XP1: CONN-10-IDC; ML10
XP2, XP3: CONN-3-NORMAL; MA03-1
XP4, XP5: CONN-6-NORMAL; MA03-2

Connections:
+15V: C1.+, R1.2, R3.1, XP4.1, XP4.3, XP4.5
-15V: C2.-, R2.2, R4.1, XP5.2, XP5.4, XP5.6
GND: C1.-, C2.+, HL1.K (C), HL2.A, XP1.2, XP1.4, XP4.2, XP4.4, XP4.6, XP5.1, XP5.3, XP5.5
unnamed: HL1.A, R3.2
unnamed: R1.1, XP1.1
unnamed: R2.1, XP1.3
unnamed: HL2.K (C), R4.2
unnamed: XP1.5, XP2.1
unnamed: XP1.7, XP2.2
unnamed: XP1.10, XP2.3
unnamed: XP1.6, XP3.1
unnamed: XP1.8, XP3.2
unnamed: XP1.9, XP3.3

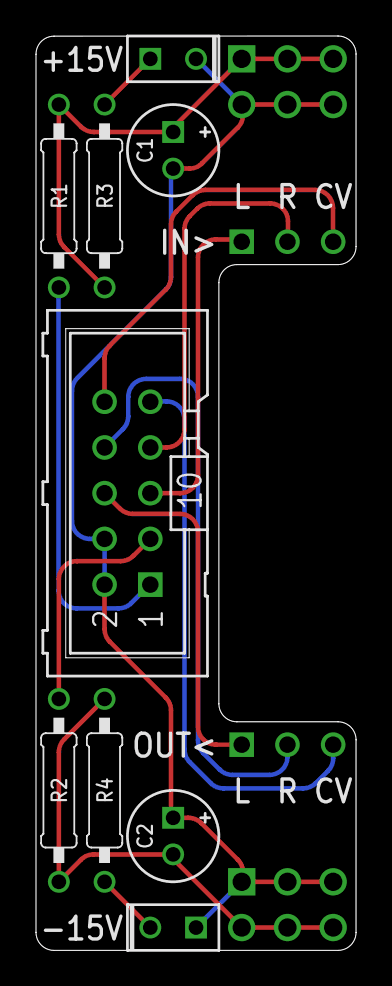
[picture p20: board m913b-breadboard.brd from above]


Board: 2 copper layers, 17.8 x 50.8 mm, 16 parts (4 on the bottom side), 13 nets.

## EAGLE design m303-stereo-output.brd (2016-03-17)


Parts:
C1, C2, C5, C6, C19, C20: 22P(TH); C050-024X044
C3, C4: 10U/35V; E2-5
C7, C8, C9, C10, C15, C16, C17, C18, C23, C24, C25: 100N(TH); C050-024X044
C11, C13: 33U/25V; E2,5-7
C12, C14, C21, C22: 100N(FILM); C050-025X075
DA1, DA2: NJM2068D; DIP-8
DA3: LA6515; SIL10
DA4: LM2903N; DIP-8
HL1: RED/BLUE(2MMX5MM,CC); LED2X5-3PIN
L1, L2: BL01RN1A1F1J; BL01RN1A
O1: 450-AA150(15MM,D,BLACK); EMPTY
O2: 450-CP156(15MM,BLACK/WHITE); EMPTY
PCB1: M303 rev.C; ST2-BOARD-50-END
R1, R2, R3, R4, R5, R6, R7, R9, R10, R11, R28: 10K(TH); R-0207/10
R8: 2A10K; RV11-DUAL
R12, R13: 33K(TH); R-0207/10
R14, R15: 10R(TH); R-0207/10
R16, R17: 2R(TH); R-0207/10
R18, R20: 10M(TH); R-0207/10
R19, R21: 100K(TH); R-0207/10
R22, R23: 47K(TH); R-0207/10
R24: 330K(TH); R-0207/10
R25: 22K(TH); R-0207/10
R26: 4K7(TH); R-0207/10
R27: 100R(TH); R-0207/10
R29: 2K2(TH); R-0207/10
R30: 1K8(TH); R-0207/10
U1, U2: SCREW-M2X8; EMPTY
U3, U4: NUT-M2-SELFLOCK; EMPTY
U5: FX2-20S-1.27DS; EMPTY
U6: ERM1-5MM; EMPTY
VD1: DF01M; MDIP-4
VD2, VD3: 1N4148; DO35-7
VT1: BC548; TO92
XS1: 35RAPC4BHN2; 35RAP

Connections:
+15V: C3.+, C7.2, C9.2, C15.2, C17.2, DA1.8 (V+), DA2.8 (V+), DA3.10 (V+), DA4.8 (V+), L1.2, R18.2, R20.2, R25.2, VD1.3 (C)
-15V: C4.-, C8.1, C10.1, C16.1, C18.1, DA1.4 (V-), DA2.4 (V-), DA3.5 (V-), DA4.4 (V-), HL1.K, L2.2, VD1.4 (A), VT1.3 (E)
GND: C3.-, C4.+, C7.1, C8.2, C9.1, C10.2, C15.1, C16.2, C17.1, C18.2, C21.1, C22.1, C25.1, DA1.3 (IN+), DA1.5 (IN+), DA2.3 (IN+), DA2.5 (IN+), PCB1.B4 (GND), PCB1.B5 (GND), PCB1.B6 (GND), PCB1.B7 (GND), PCB1.B8 (GND), PCB1.BSENSE (SENSE), R8.1 (CCW), R8.1' (CCW), R10.1, R11.1, R19.1, R21.1, R24.1, R27.1, R29.2, R30.2, XS1.1 (S)
LMIX: C1.1, DA1.6 (IN-), PCB1.ALMIX (LMIX), R1.1, R9.1
unnamed: L1.1, PCB1.A+15 (P+15V), PCB1.B+15 (P+15V)
unnamed: DA3.6 (IN+), R8.2 (W)
unnamed: L2.1, PCB1.A-15 (P-15V), PCB1.B-15 (P-15V)
unnamed: C1.2, DA1.7 (OUT), R1.2, R3.1
unnamed: C2.2, DA1.1 (OUT), R2.2, R4.1
unnamed: DA3.4 (IN+), R8.2' (W)
unnamed: C13.-, C14.2, C24.1, R8.3 (CW)
unnamed: C19.2, DA3.1 (SENSE), R12.2, R14.2, R16.2, VD1.1 (AC1), XS1.2 (T)
unnamed: C19.1, DA3.3 (IN-), R10.2, R12.1
unnamed: R22.2, VD2.A
unnamed: DA3.2 (OUT), R14.1
unnamed: C11.-, C12.2, C23.1, R8.3' (CW)
unnamed: C21.2, R16.1
unnamed: C23.2, R18.1, R19.2, R22.1
unnamed: C24.2, R20.1, R21.2, R23.1
unnamed: R23.2, VD3.A
unnamed: C25.2, DA4.3 (IN+), DA4.5 (IN+), R24.2, VD2.C, VD3.C
unnamed: C20.1, DA3.7 (IN-), R11.2, R13.1
unnamed: DA4.2 (IN-), R26.1, R27.2
unnamed: C20.2, DA3.9 (SENSE), R13.2, R15.2, R17.2, VD1.2 (AC2), XS1.3 (R)
unnamed: DA4.1 (OUT), HL1.A2, R30.1, VT1.1 (C)
unnamed: PCB1.ARFBK (RFBK), PCB1.BINR (INR), R7.2
unnamed: PCB1.ALFBK (LFBK), PCB1.BINL (INL), R9.2
unnamed: DA3.8 (OUT), R15.1
unnamed: C22.2, R17.1
unnamed: DA4.6 (IN-), R25.1, R26.2
unnamed: DA4.7 (OUT), HL1.A1, R28.2, R29.1
unnamed: R28.1, VT1.2 (B)
unnamed: C5.1, DA2.6 (IN-), R3.2, R5.1
unnamed: C5.2, C11.+, C12.1, DA2.7 (OUT), R5.2
unnamed: C6.1, DA2.2 (IN-), R4.2, R6.1
unnamed: C6.2, C13.+, C14.1, DA2.1 (OUT), R6.2
RMIX: C2.1, DA1.2 (IN-), PCB1.ARMIX (RMIX), R2.1, R7.1


Board: 2 copper layers, 100.0 x 50.0 mm, 76 parts (0 on the bottom side), 37 nets.

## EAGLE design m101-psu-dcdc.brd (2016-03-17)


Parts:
C1, C2, C3, C5: 33U/50V; E3,5-8
C4: 10U/35V; E2-5
C6, C9: 100N(TH); C050-024X044
C7, C8: 39U/35V; E3,5-8
C10, C11: 100N(FILM); C050-025X075
DA1: NE555P; DIP-8
HL1: RED/BLUE(2MMX5MM,CC); LED2X5-3PIN
L1: BL01RN1A1F1J; BL01RN1A
PCB1: M101 rev.B; ST2-BOARD-50-PSU
R1, R2, R4, R6, R7, R10, R11: 100K(TH); R-0207/10
R3: 10K(TH); R-0207/10
R5, R8, R9: 1K5(TH); R-0207/10
S1: JUMPER-1POS-SOLDER; JP1-SOLDER
SA1: MHS122K; APEM-MHS122K
U1: FX2-20P-1.27DS; EMPTY
U2: SHHN000A3CL41Z; DC/DC-C1
U3: G3VM-62C1; DIL08
U4: ERM1-5MM; EMPTY
U5, U6: SCREW-M2X8; EMPTY
U7, U8: NUT-M2-SELFLOCK; EMPTY
VD1: DF01M; MDIP-4
VD2: BAT46; DO35-7
XS1: PJ-051AH

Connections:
-15V: C4.-, C6.1, C8.-, C9.1, C11.1, DA1.1 (V-), R3.1, R7.1, R8.2, U2.6 (V-), U3.7 (S2)
GND: C7.-, C8.+, C9.2, C10.1, C11.2, DA1.4 (!RESET), DA1.8 (V+), HL1.A1, PCB1.ACV1' (CV1'), PCB1.ACV2' (CV2'), PCB1.B4' (GND), PCB1.B5' (GND), PCB1.B6' (GND), PCB1.B7' (GND), PCB1.B8' (GND), PCB1.BOUTL' (OUTL), PCB1.BOUTR' (OUTR), R1.2, R2.2, R6.1, R7.2, R10.1, R11.2, U2.5 (GND)
unnamed: R5.2, U3.1 (A)
unnamed: VD1.1 (AC1), XS1.3 (S)
unnamed: C1.-, C2.-, C3.-, C5.-, S1.1, SA1.1' (1), SA1.2, U2.2 (IN-), VD1.4 (A)
unnamed: PCB1.ALFBK' (LFBK'), R1.1
unnamed: PCB1.ARFBK' (RFBK'), R2.1
unnamed: C6.2, DA1.5 (CONTROL)
unnamed: DA1.3 (OUT), U3.4 (C)
unnamed: PCB1.A+15' (P+15V), PCB1.B+15' (P+15V), R9.2, R10.2, U3.6 (S1)
unnamed: U3.2 (C), U3.3 (A)
unnamed: C4.+, DA1.2 (!TRIGGER), DA1.6 (THRESHOLD), R4.1, VD2.A
unnamed: VD1.2 (AC2), XS1.1
unnamed: PCB1.A-15' (P-15V), PCB1.B-15' (P-15V), R11.1, U3.8 (S1)
unnamed: HL1.K, R8.1
unnamed: HL1.A2, R9.1
unnamed: C7.+, C10.2, R6.2, U2.4 (V+), U3.5 (S2)
unnamed: S1.2, SA1.CMN (CM), SA1.CMN' (CM), U2.3 (EN)
unnamed: C1.+, C2.+, L1.1, VD1.3 (C)
unnamed: C3.+, C5.+, L1.2, U2.1 (IN+)
SENSE: PCB1.BSENSE' (SENSE'), R3.2, R4.2, R5.1, VD2.C


Board: 2 copper layers, 100.0 x 50.0 mm, 39 parts (1 on the bottom side), 21 nets.

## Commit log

2015-11-15 Initial commit
    + M2101 - PSU DC/DC
    + M2201 - Stereo Input
    + M2301 - Stereo Output
    [m2101-psu-dcdc.brd, m2101-psu-dcdc.sch, m2201-stereo-input.brd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]
2015-11-15 Add (dummy) FX2 connectors to sch
    [m2201-stereo-input.brd, m2201-stereo-input.sch, m2301-stereo-output.brd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]
2015-11-25 D2101 initial commit
    [d2101-lofi-delay.brd, d2101-lofi-delay.sch]
2015-11-25 Fix PJ-051AH pinout (#1)
    [m2101-psu-dcdc.brd, m2101-psu-dcdc.sch]
2015-11-25 Board rev.A -> rev.B
    [m2101-psu-dcdc.brd, m2101-psu-dcdc.sch]
2015-11-25 Add Z00001, Z00002, Z00003-5, M21012 and M21013-5 panels
    [m21012.dxf, m21013-5.dxf, z00001.dxf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]
2015-11-25 Add w120-6045 panel (D-shaft spacer)
    [w120-6045.dxf]
2015-11-25 Add M21016 panels with switch and without switch
    [m21016-no-switch.dxf, m21016-switch.dxf]
2015-12-01 D2101 done
    [d2101-lofi-delay.brd, d2101-lofi-delay.sch]
2015-12-04 Replace switchable delay potentiometers with single ones
    [d2101-lofi-delay.brd, d2101-lofi-delay.sch]
2015-12-04 Minor routing adjustment
    [d2101-lofi-delay.brd]
2015-12-04 Signal indicator refactoring (#5) + no noise when no jack inserted (#6)
    [m2201-stereo-input.brd, m2201-stereo-input.sch]
2015-12-04 Mouser part number fix
    [m2201-stereo-input.brd, m2201-stereo-input.sch]
2015-12-04 Change headphone amplifier gain to +15 dB #4
    [m2301-stereo-output.brd, m2301-stereo-output.sch]
2015-12-04 Renumber components
    [m2201-stereo-input.brd, m2201-stereo-input.sch]
2015-12-08 m2301 PCB update
    [m2301-stereo-output.brd, m2301-stereo-output.sch]
2015-12-08 Replace 10R resistors with ferrite beads Replace 47u/35V with 33u/25V
    [m2201-stereo-input.brd, m2201-stereo-input.sch]
2015-12-08 Replace 10R with ferrite bead Replace 47u/35V with 33u/25V
    [d2101-lofi-delay.brd, d2101-lofi-delay.sch]
2015-12-08 a2401 Diode Distortion schematic
    [a2401-diode-distortion.brd, a2401-diode-distortion.sch]
2015-12-08 a2402 4069 distortion schematic
    [a2402-4069-distortion.brd, a2402-4069-distortion.sch]
2015-12-10 Replaced bypass switch with blend potentiometer
    [a2401-diode-distortion.brd, a2401-diode-distortion.sch]
2015-12-13 a2402 rename
    [a2402-4069-overdrive.brd, a2402-4069-overdrive.sch]
2015-12-13 a2402 routing
    [a2402-4069-overdrive.brd, a2402-4069-overdrive.sch]
2015-12-13 Replace feedback switch with MJS22R
    [d2101-lofi-delay.brd, d2101-lofi-delay.sch]
2015-12-14 d2101 controls placement fix
    [d2101-lofi-delay.brd, d2101-lofi-delay.sch]
2015-12-14 d2102 SpinSemi FX Board
    [d2102-spinsemi-fx.brd, d2102-spinsemi-fx.sch]
2015-12-14 Changed 47u/16V -> 10u/35V
    [d2101-lofi-delay.brd, d2101-lofi-delay.sch]
2015-12-14 a2401 diode distortion board
    [a2401-diode-distortion.brd, a2401-diode-distortion.sch]
2015-12-16 m901 vu meter schematic and routing
    [m901-vu-meter.brd, m901-vu-meter.sch]
2015-12-16 a2401 -> a401 rename
    [a401-diode-distortion.brd, a401-diode-distortion.sch]
2015-12-16 a2402 -> a402 rename
    [a402-4069-overdrive.brd, a402-4069-overdrive.sch]
2015-12-16 d2101 -> d101 rename
    [d101-lofi-delay.brd, d101-lofi-delay.sch]
2015-12-16 d2102 -> d102 rename
    [d102-spinsemi-fx.brd, d102-spinsemi-fx.sch]
2015-12-16 m2301 -> m301 rename
    [m301-stereo-output.brd, m301-stereo-output.sch]
2015-12-22 d701 initial design
    [d701-vs1053-synth.brd, d701-vs1053-synth.sch]
2015-12-23 d701 routing update
    [d701-vs1053-synth.brd, d701-vs1053-synth.sch]
2016-03-01 M2201 -> M201 Rename
    [m201-stereo-input.brd, m201-stereo-input.sch]
2016-03-01 M201 In T/H
    [m201-stereo-input.brd, m201-stereo-input.sch]
2016-03-02 M301 Update
    [m301-stereo-output.brd, m301-stereo-output.sch]
2016-03-02 M301 Routing
    [m301-stereo-output.brd]
2016-03-02 A202 4Band EQ Schematics and Board
    [a202-4-band-eq.brd, a202-4-band-eq.sch]
2016-03-03 A202 Routing Update
    [a202-4-band-eq.brd]
2016-03-03 A101 Fader Schematic and Board
    [a101-fader.brd, a101-fader.sch]
2016-03-03 A201 WIP
    [a201-kill-eq.brd, a201-kill-eq.sch]
2016-03-03 Add Potentiometer Knobs
    [a202-4-band-eq.brd, a202-4-band-eq.sch]
2016-03-03 Add Knobs
    [d101-lofi-delay.brd, d101-lofi-delay.sch]
2016-03-04 A201 Routing Update
    [a201-kill-eq.brd, a201-kill-eq.sch]
2016-03-04 Module Footprint Update
    [a201-kill-eq.brd, a201-kill-eq.sch]
2016-03-04 D101 Update
    [d101-lofi-delay.brd, d101-lofi-delay.sch]
2016-03-06 PCB Update
    [m201-stereo-input.brd, m201-stereo-input.sch]
2016-03-06 M201 -> M202
    [m202-stereo-input.brd, m202-stereo-input.sch]
2016-03-06 A401 -> A405
    [a405-diode-distortion.brd, a405-diode-distortion.sch]
2016-03-06 M301 -> M303
    [m303-stereo-output.brd, m303-stereo-output.sch]
2016-03-06 A101 -> A111
    [a111-fader.brd, a111-fader.sch]
2016-03-06 A201 -> A212
    [a212-kill-eq.brd, a212-kill-eq.sch]
2016-03-06 A202 -> A210
    [a210-4-band-eq.brd, a210-4-band-eq.sch]
2016-03-06 A402 -> A410
    [a410-4069-overdrive.brd, a410-4069-overdrive.sch]
2016-03-06 D701 -> D709
    [d709-vs1053-synth.brd, d709-vs1053-synth.sch]
2016-03-06 D101 -> D104
    [d104-lofi-delay.brd, d104-lofi-delay.sch]
2016-03-06 D102 -> D108
    [d108-spinsemi-fx.brd, d108-spinsemi-fx.sch]
2016-03-06 M901 -> M907
    [m907-vu-meter.brd, m907-vu-meter.sch]
2016-03-06 PSU PCB Update
    [m2101-psu-dcdc.brd, m2101-psu-dcdc.sch]
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2016-03-09 M913 Dev Adapter PCB & Schematics
    [m913-dev-adapter.brd, m913-dev-adapter.sch]
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2016-03-09 Add missing female connectors
    [m913b-breadboard.brd, m913b-breadboard.sch]
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2016-03-09 Add ERM1-4MM for LEDs
    [m913b-breadboard.brd, m913b-breadboard.sch]
2016-03-09 M913 Component Values Update
    [m913b-breadboard.brd, m913b-breadboard.sch]
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2016-03-14 Fix M913b Board
    [m913b-breadboard.brd]
2016-03-14 Fix copyright positioning
    [m913b-breadboard.brd]
2016-04-01 D709 Update to use F1042
    [d709-vs1053-synth.brd, d709-vs1053-synth.sch]
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2016-06-02 M907 LED VU color update
    [m907-vu-meter.brd, m907-vu-meter.sch]
2016-06-06 M907: Change 100R to 180R
    [m907-vu-meter.brd, m907-vu-meter.sch]
2016-06-11 D709 LED Color Change
    [d709-vs1053-synth.brd, d709-vs1053-synth.sch]

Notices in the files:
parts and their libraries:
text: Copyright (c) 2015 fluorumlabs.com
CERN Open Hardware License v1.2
